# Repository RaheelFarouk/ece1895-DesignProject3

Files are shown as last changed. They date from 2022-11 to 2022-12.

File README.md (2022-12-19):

# **Design Project 3 – Designing a Live Telemetry System**

# Design Overview

This project was developed for ECE 1895 – Junior Design at the University of Pittsburgh.
 The purpose of this project was to develop a Live Telemetry system for use in Automotive and Motorsport applications. The live telemetry system is used to be able to analyse data from sensors and actuators on the vehicle remotely and in real time. It consists of a device called the Vehicle Telemetry Module (VTM) that goes inside a vehicle and connects to the CAN bus on the vehicle. The CAN bus is a network protocol used in automotive applications to send data and allow multiple devices to communicate with each other two wires. This Vehicle Telemetry Module then uses ethernet to connect to a 4G Router to send this data over the internet to a server that receives that data, and forwards it to the client (the data analysis workstation).

### Timeline

This was a six week project and this was the timeline I followed for the project:

- 1st week: Prototype and make CAN Bus code
- 2nd week: Start working on Ethernet Code
- 3rd week: Combine both CAN and Ethernet Code
- 4th week: Start working on server-side code to retrieve data
- 5th week: Test the system
- 6th week: Continue testing and debugging and 3D print enclosure

In the six weeks I was also able to work on a custom PCB for the vehicle telemetry module and also write a basic MATLAB script for the client side to receive data from the server.

### Vehicle Telemetry Module Considerations

The initial considerations for the vehicle telemetry module were as follows:

For the microprocessor I chose an ATMEGA328P, as it was the chip used in an Arduino and had both enough memory and processing power for the initial application. In addition, I also had an Arduino UNO available and thought it would be a good prototyping platform to get started on.

For the CAN bus communication, I chose an MCP2515 as the CAN controller and a MCP2551 for the CAN transceiver. Again, this decision was influenced by the fact that there was already a CAN shield developed for the Arduino and I had prior experience with using the SPI bus which is what this shield used to communicate with the Arduino. For this I used the autowp-mcp2515 library found here: [https://www.arduino.cc/reference/en/libraries/autowp-mcp2515/](https://www.arduino.cc/reference/en/libraries/autowp-mcp2515/)

For the Ethernet module I chose to use the Arduino Ethernet shield V2. This shield also used SPI to communicate with the ATMEGA328 Chip. Therefore, I decided to use it. I used the getting started guide on the Arduino website to get this ethernet shield to work with the Arduino. [https://docs.arduino.cc/tutorials/ethernet-shield-rev2/udp-send-receive-string](https://docs.arduino.cc/tutorials/ethernet-shield-rev2/udp-send-receive-string)

### Server Code Considerations

For the server code I decided to use python. This was because I had used python in the past and I found out that python already and an in-built library for UDP communication. Since it was in-built it also had great documentation that I was able to make use of. This was a fairly straight forward decision as I had never done anything like this in the past and didn't really know what other options there was, in the future I will look into this and see if there are any better options for the server-side code. [https://wiki.python.org/moin/UdpCommunication](https://wiki.python.org/moin/UdpCommunication)
[https://pythontic.com/modules/socket/udp-client-server-example](https://pythontic.com/modules/socket/udp-client-server-example)

### Client Code Considerations

At this time, I haven't decided what to do with the client-side interface; however, I had time at the end to do some basic coding in MATLAB to make a script that is able to connect to the server and get some data from the server.

# Preliminary Design Verification

## Hardware

For the initial prototype stage, I used an Arduino UNO with the Ethernet shield and the CAN shield.

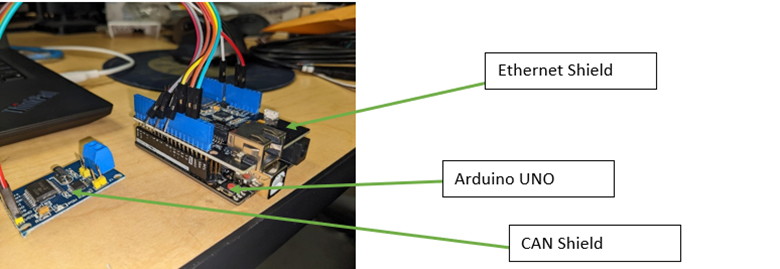
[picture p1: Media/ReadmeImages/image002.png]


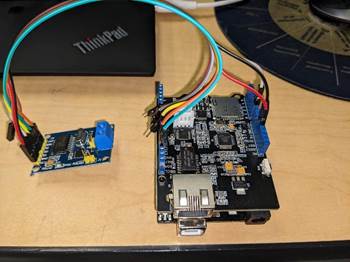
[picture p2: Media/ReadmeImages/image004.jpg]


## Software

I split this prototyping stage up into three parts. Firstly, I got the Arduino to read data from the CAN bus. Secondly, I got the Arduino to be able to send messages using UDP to a simple receive script that I made on the server. Thirdly, I combined the code to receive data from the CAN bus and then send it using the UDP protocol to the simple server script.

#### Reading CAN data using the Arduino

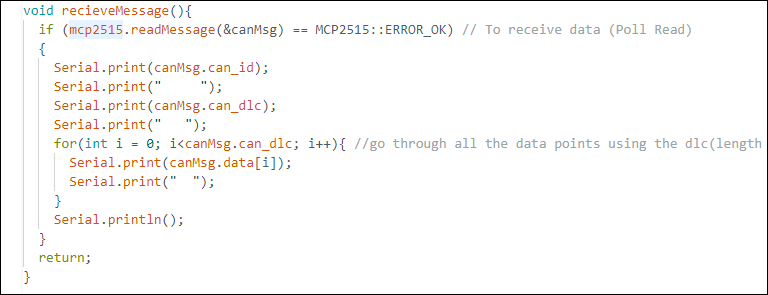
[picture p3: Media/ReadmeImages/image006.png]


_Receive Code Snippet_

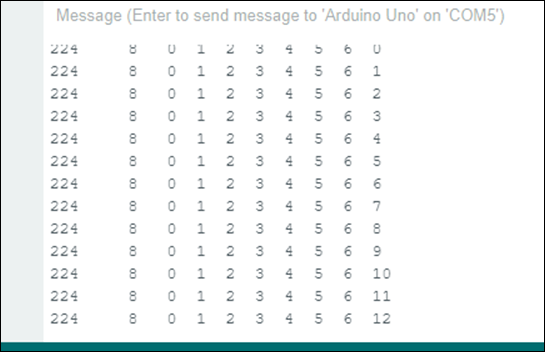
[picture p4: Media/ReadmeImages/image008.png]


_Serial Output_

As you can see in the above two images, I was able to read data from the CAN bus. The data being transferred on the CAN bus is just a basic counter in the last byte.

#### Sending Data using the UDP Protocol

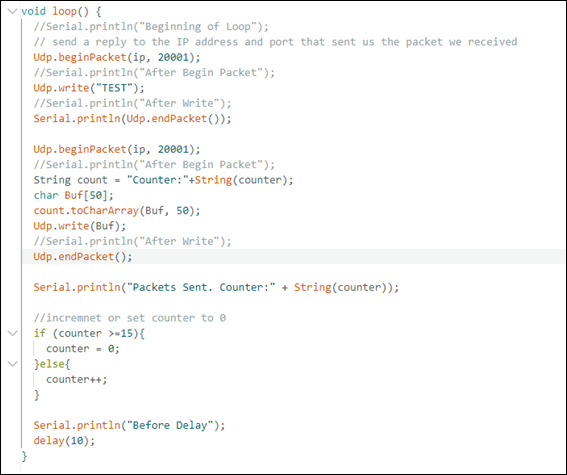
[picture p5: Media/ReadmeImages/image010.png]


_UDP Send Test code snippet_

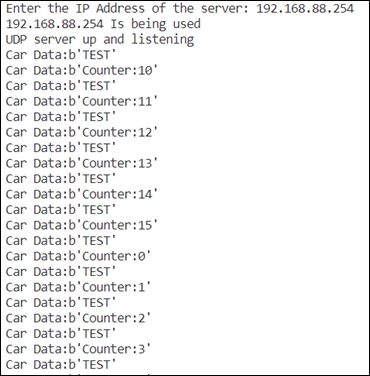
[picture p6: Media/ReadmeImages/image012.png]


_Console output on the server_

#### Receiving CAN Data and Sending it Using the UDP Protocol

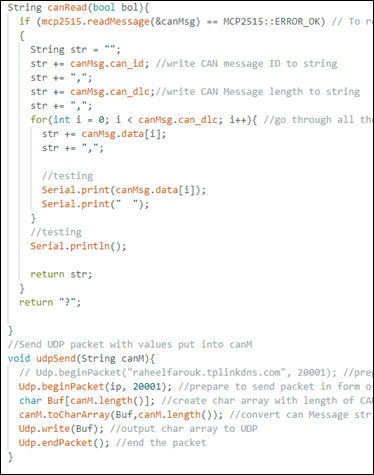
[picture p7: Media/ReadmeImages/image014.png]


_CAN data receive and send code snippet._

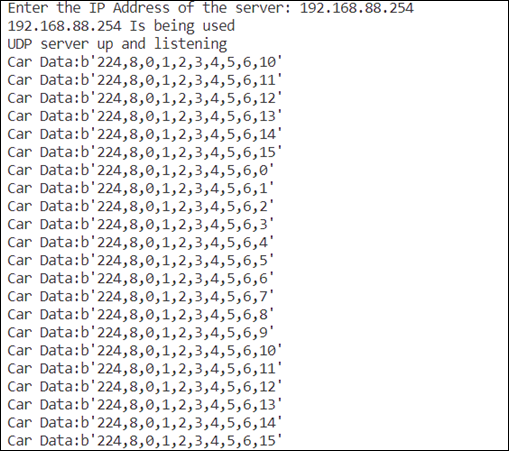
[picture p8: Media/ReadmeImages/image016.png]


 _Console output on the server._

# Design Implementation

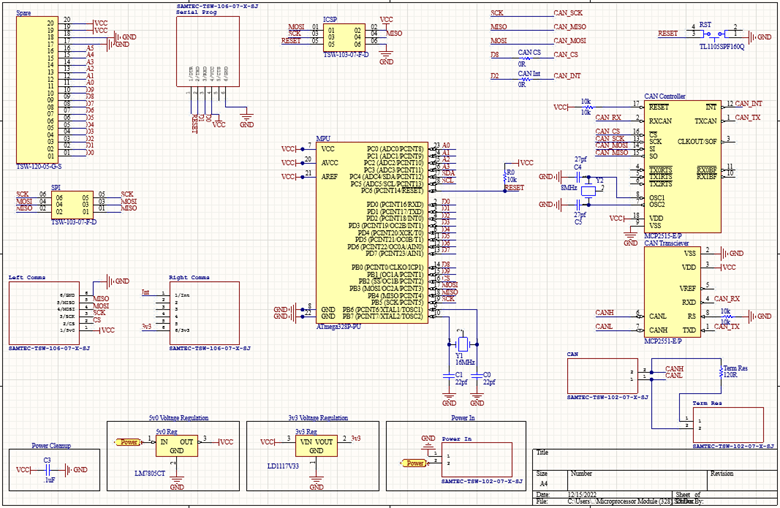
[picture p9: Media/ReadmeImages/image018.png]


_Schematic for the Microprocessor and CAN Chips_

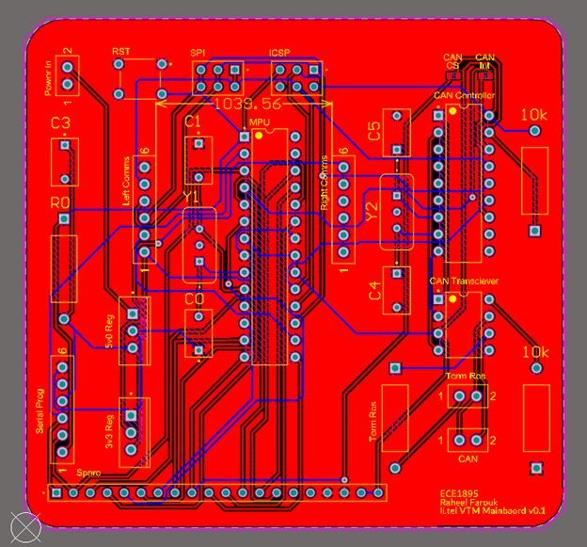
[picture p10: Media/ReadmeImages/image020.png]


_PCB Layout for the Microprocessor and CAN Chips_

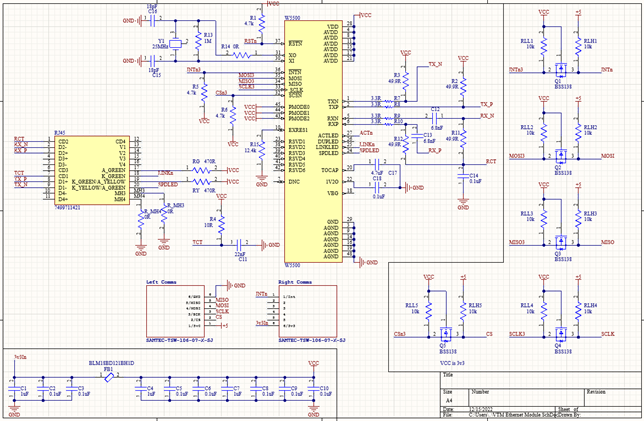
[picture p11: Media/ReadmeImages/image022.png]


_Schematic for the ethernet module_

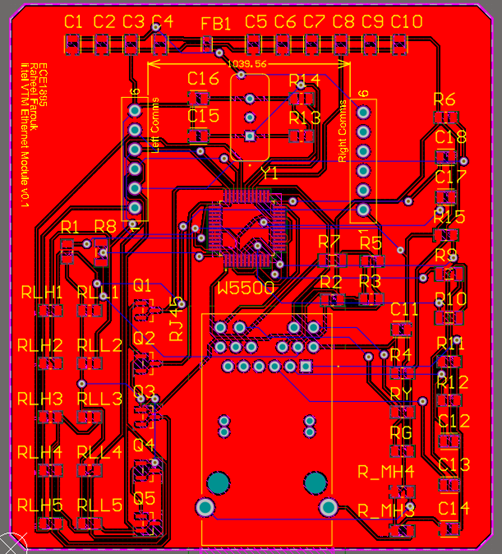
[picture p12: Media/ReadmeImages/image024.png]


_PCB Layout for the ethernet module_

# Design Testing

### Assembled Boards

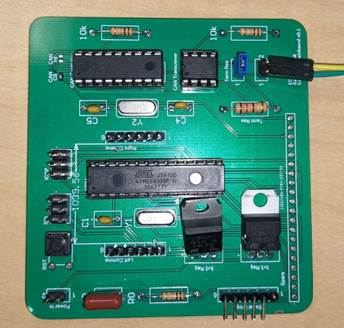
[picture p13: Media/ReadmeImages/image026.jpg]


_Main board with ATMEGA328 and CAN Chips_

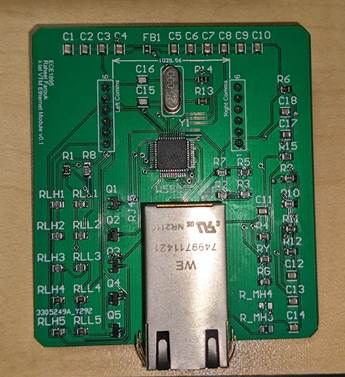
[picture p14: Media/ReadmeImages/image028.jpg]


_Ethernet Board_

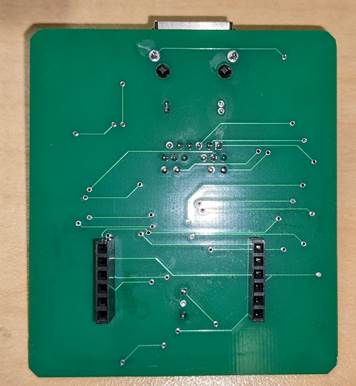
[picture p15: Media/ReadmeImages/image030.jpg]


_Underside of Ethernet board_

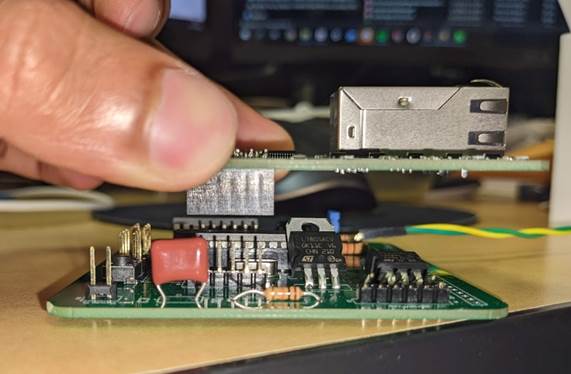
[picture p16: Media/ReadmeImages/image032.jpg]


_Plugging in the ethernet boards to the main board_

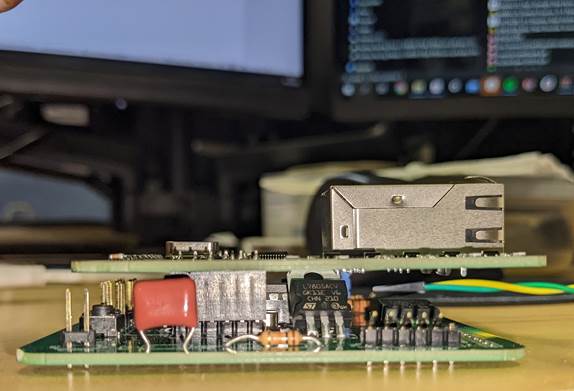
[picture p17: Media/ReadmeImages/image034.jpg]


_The complete stack_

### Testing

To test out the system I carried out the same tests that I did when initially prototyping the system. I used another development board to simulate the CAN bus on a vehicle and send CAN messages to my Vehicle Telemetry Module. I sent a basic message with a counter that sends an integer from 0 to 15 in the last byte of the CAN message. The development board that is set to simulate the car is set to send a CAN message every 50 milliseconds.



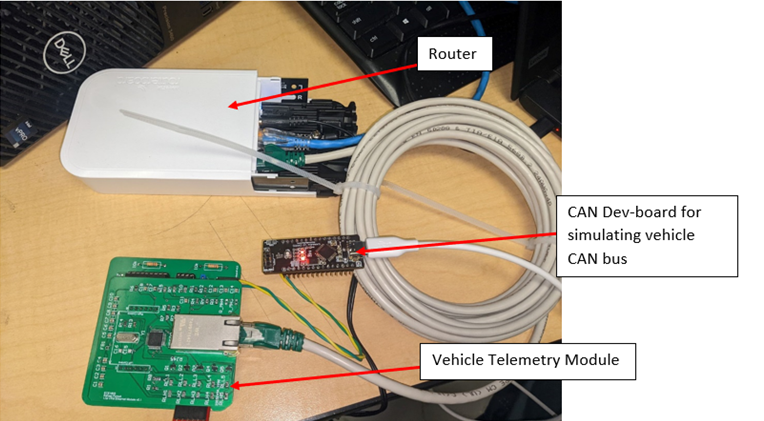
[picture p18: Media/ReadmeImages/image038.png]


_The test setup_

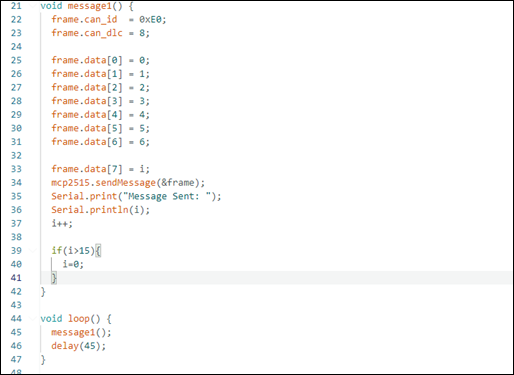
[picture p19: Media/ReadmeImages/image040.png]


 _Code for the CAN dev-board that is simulating the car_

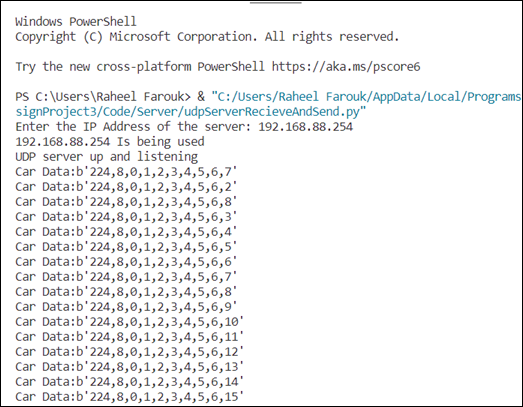
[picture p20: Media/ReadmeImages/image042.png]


 _Console output of the running code_

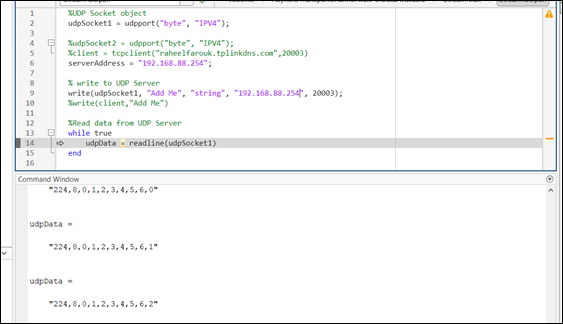
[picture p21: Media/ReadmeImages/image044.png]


 _Basic MATLAB Script reading broadcasted data from the server_

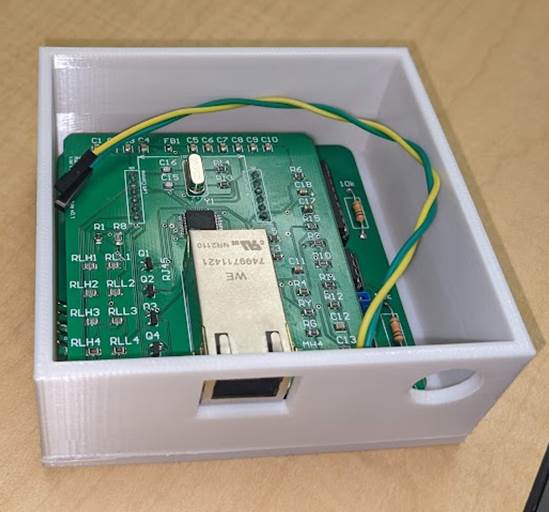
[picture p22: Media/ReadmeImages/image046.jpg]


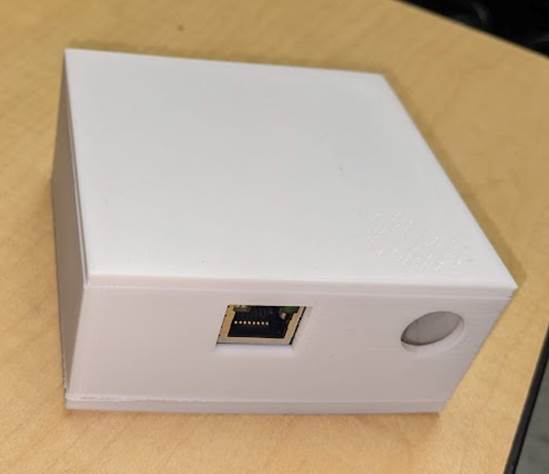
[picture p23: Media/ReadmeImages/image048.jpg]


 _3D printed enclosure for the Vehicle Telemetry Module_

# Summary, Conclusions and Future Work

In summary, the system works as it is intended. A few things that I would like to accomplish in the future is to make both my PCBs smaller and also possibly integrate it into one PCB. I had not taken into account the height and positions of certain components and had to therefore bend some components out of the way; this is something that I intent to fix in future versions. Another thing I would like to do is test out the data transfer rate at which messages are starting to be missed or lost. A future addition to the server-side code is to add a GUI and to make a client software to analyse the data. 

# Folder Structure

All the code for the live telemetry system is in the *Code* folder, the Vehicle Telemetry Code is inside the *Car* folder, the server code in the *Server* folder and the client code in the *Client* folder. The Altium PCB projects and enclosure CAD files are in the hardware folder. Any reference documents, schematics and libraries are in the *Datasheets and Reference Docs* folder.

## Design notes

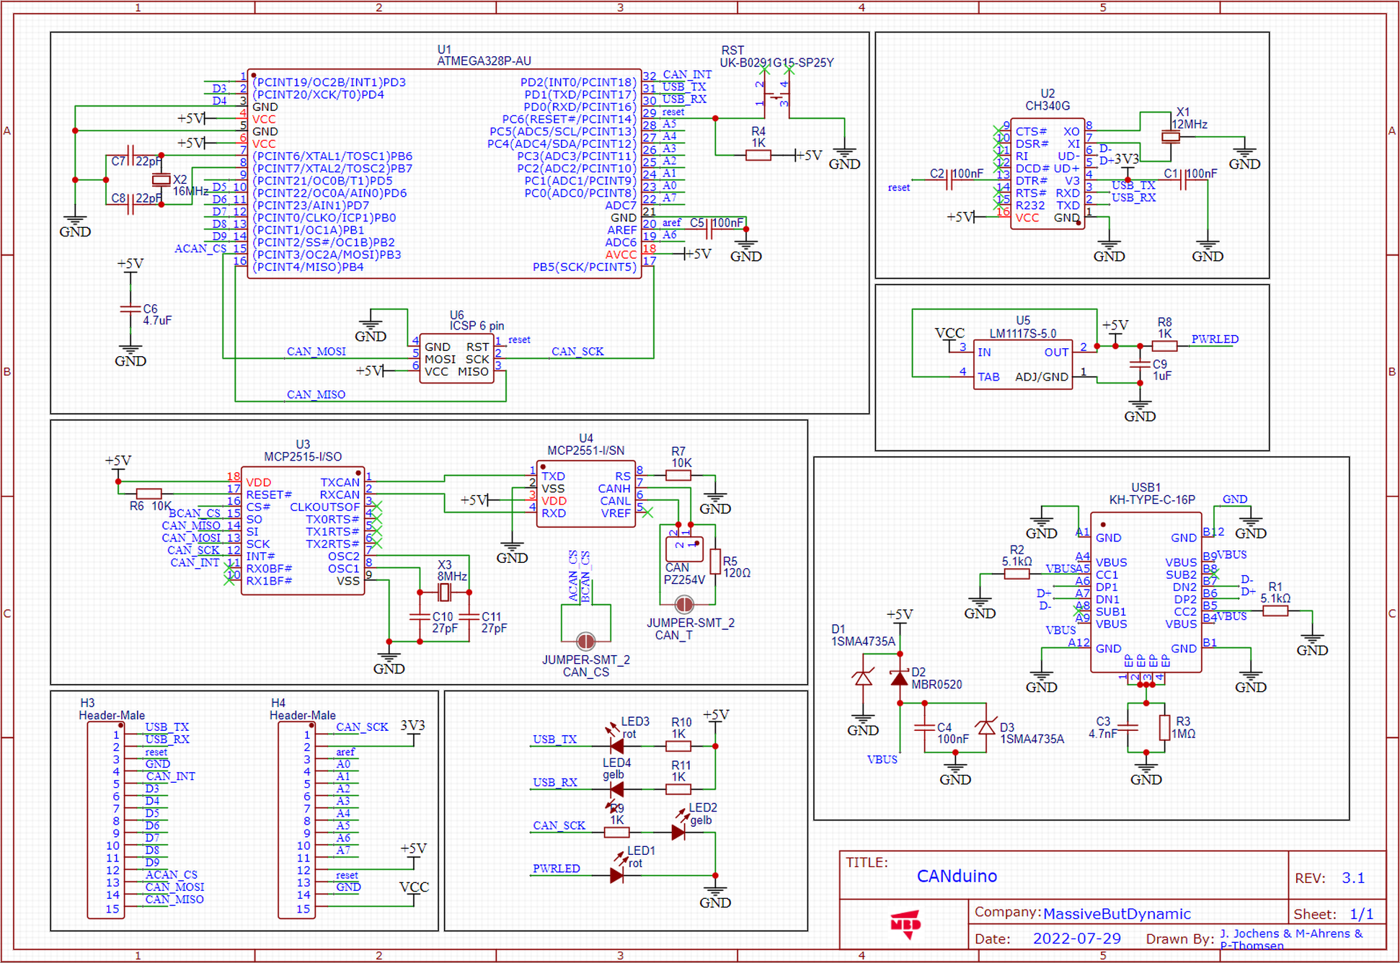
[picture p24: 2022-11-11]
Datasheets and Reference Docs/CANduino Schematic.png

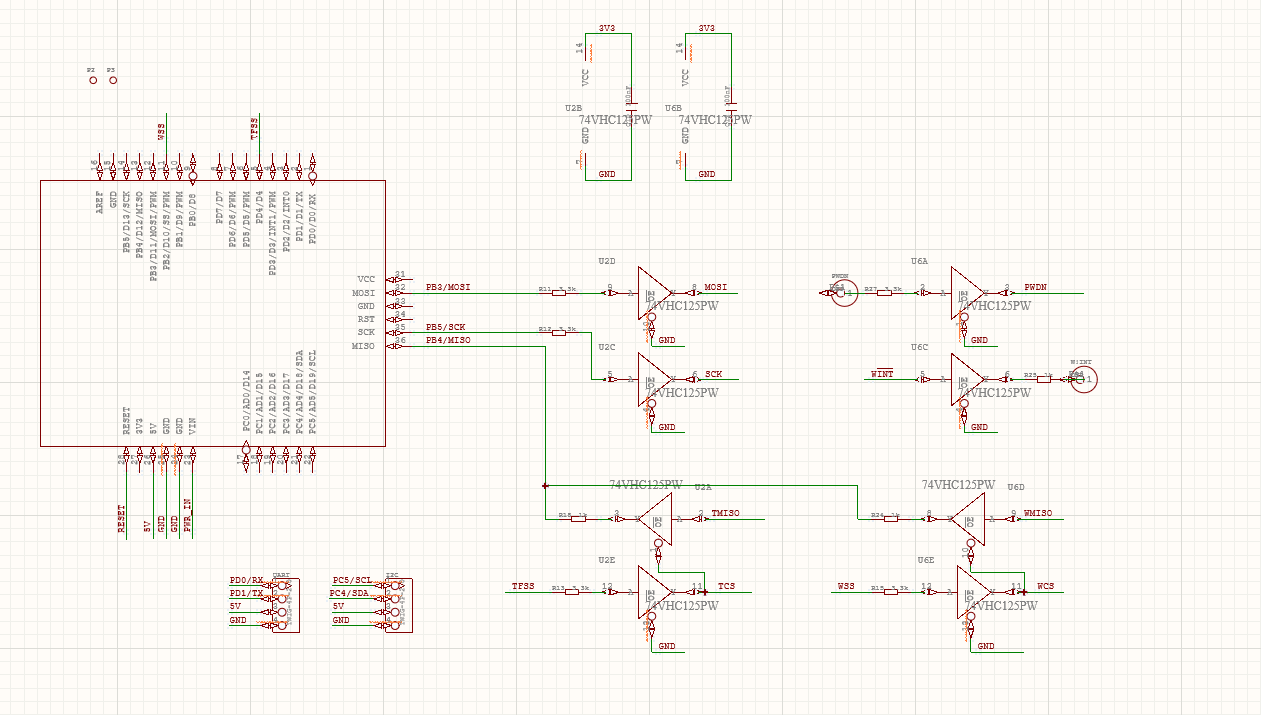
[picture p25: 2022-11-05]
Datasheets and Reference Docs/Arduino Ethernet Shield v2.0/Images/Screenshot 2022-10-31 183155.png

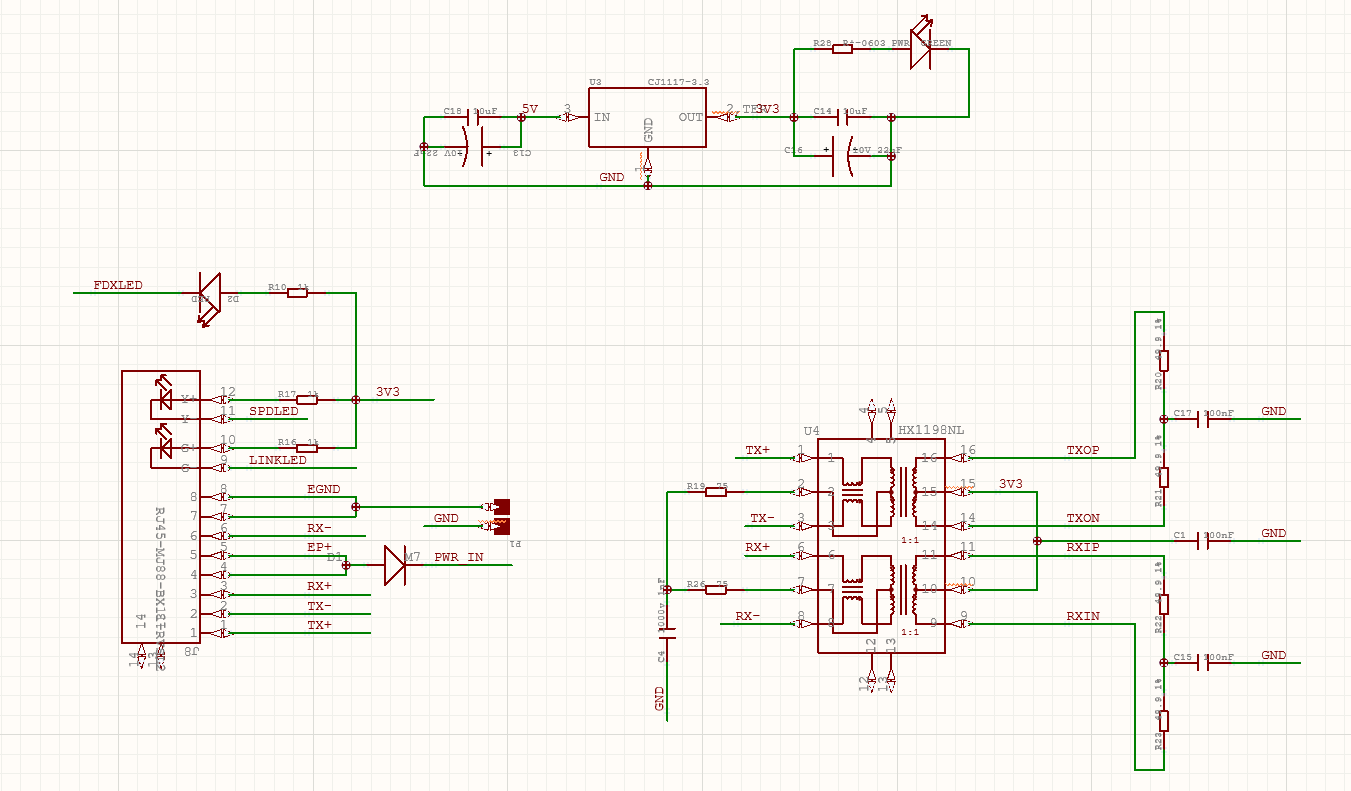
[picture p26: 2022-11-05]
Datasheets and Reference Docs/Arduino Ethernet Shield v2.0/Images/Screenshot 2022-10-31 183148.png

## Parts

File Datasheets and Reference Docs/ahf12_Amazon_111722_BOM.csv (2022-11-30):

Quantity | Link | Description | Pitt User ID | Unit Price | Extended Price
1 | https://www.amazon.com/HiLetgo-FT232RL-Converter-Adapter-Breakout/dp/B00IJXZQ7C | Serial Programmer | ahf12 | 6.49 | 6.49
1 | https://www.amazon.com/KeeYees-Channels-Converter-Bi-Directional-Shifter/dp/B07LG646VS?s=electronics | BSS138 Chip | ahf12 | 7.99 | 7.99
1 | https://www.amazon.com/uxcell-Crystal-Oscillators-Resonators-Replacements/dp/B07Y7GH8MD | Crystal Oscillator | ahf12 | 9.99 | 9.99
1 | https://www.amazon.com/Elegoo-EL-CP-004-Multicolored-Breadboard-arduino/dp/B01EV70C78 | Jumper Wires | ahf12 | 6.98 | 6.98

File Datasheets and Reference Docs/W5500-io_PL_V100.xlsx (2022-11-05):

W5500-io V100 Partlist
No | Quantity | Designator | Comment | Description | Pakage
1 | 3 | C1, C4, C7 | 1uF | 10V-5% Ceramic | CASE 0402
2 | 9 | C2, C3, C5, C6, C8, C9, C10, C14, C18 | 0.1uF | 50V-5% Ceramic | CASE 0402
3 | 1 | C11 | 22nF | 50V-5% Ceramic | CASE 0402
4 | 2 | C12, C13 | 6.8nF | 50V-5% Ceramic | CASE 0402
5 | 2 | C15, C16 | 18pF | 50V-5% Ceramic | CASE 0402
6 | 1 | C17 | 4.7uF | 16V-10%Ceramic | CASE 0805
7 | 1 | J1 | Not Mount
8 | 2 | J2, J3 | Not Mount
9 | 1 | L1 | HH-1M1608-121JT | Bead for Power Line, 120[ohm] | CASE 0603
10 | 3 | R1, R5, R6 | 4.7K | 1/10W-1% SMD | CASE 0402
11 | 4 | R2, R3, R11, R12 | 49.9R | 1/10W-1% SMD | CASE 0402
12 | 1 | R4 | 10R | 1/10W-1% SMD | CASE 0402
13 | 4 | R7, R8, R9, R10 | 3.3R | 1/10W-1% SMD | CASE 0402
14 | 1 | R13 | 1M | 1/10W-1% SMD | CASE 0402
15 | 1 | R14 | 0R | 1/10W-1% SMD | CASE 0402
16 | 1 | R15 | 12.4K | 1/10W-1% SMD | CASE 0402
17 | 1 | U1 | W5500 | WIZnet Hardwired TCP/IP Chip | W5500-LQFP48
18 | 1 | Y1 | 25MHz | X-tal 25MHz,3.2x2.5 SMD, CL=18pF | SMD3225, 4-PAD
19 | 1 | PCB | 20 X 24 (MM), 4-Layer, 1.0T, 1oz, FR-4, OSP, PCB: Matt Black, Silk: White

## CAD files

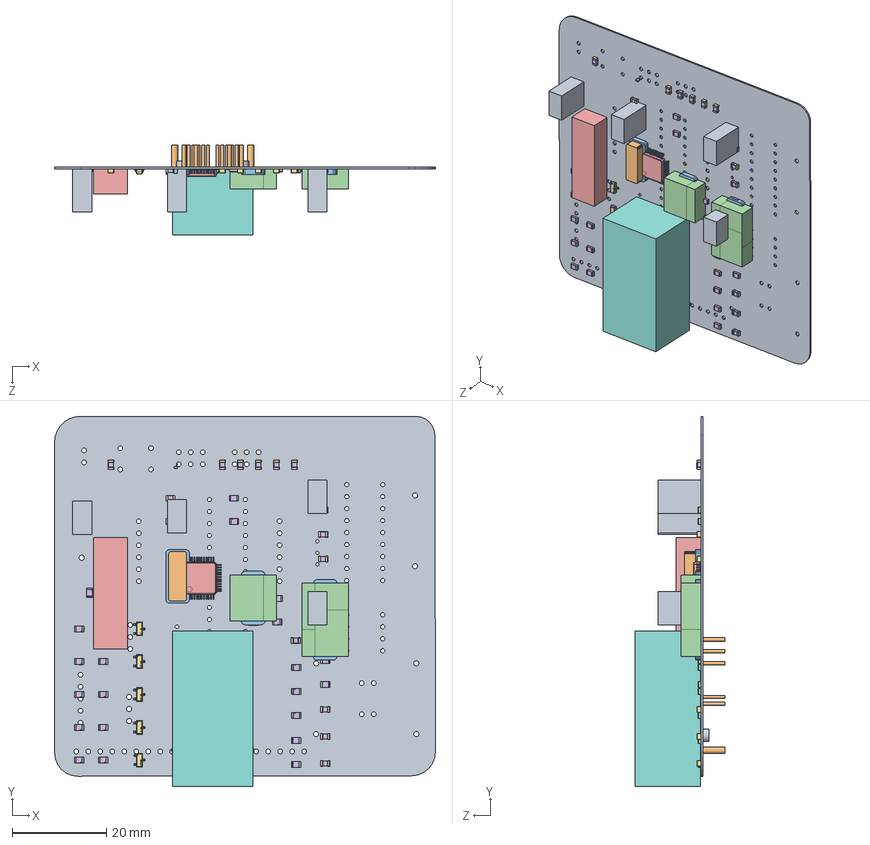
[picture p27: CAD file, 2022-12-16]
Hardware/CAD/VTM Ethernet Module.step.SLDASM
80.7 x 78.5 x 19.0 mm
Extruded.step
Extruded-0.step
1.step x 25
2.step x 25
3.step x 25
TE connectivity Logo 1 (2).step x 25
Body.step
Lugs.step
Leads.step
Extruded-1.step x 3
Extruded-2.step x 6
Extruded-3.step
Extruded-4.step x 2
1-5.step x 5
2-6.step x 5
ON Semi Logo - withoutPN.step x 5
ON Semi Logo - withoutPN - Copy.step x 5
6024908304.step
Cap_KEMET_C0805C472J3HAC_eec.step x 14
Cap_KEMET_C0805C472J3HAC_eec-7.step x 14
Cap_KEMET_C0805C472J3HAC_eec-8.step x 14
Extruded-14.step x 4

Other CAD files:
Hardware/CAD/R8.step.SLDASM
Hardware/CAD/R2.step.SLDASM
Hardware/CAD/Q4.step.SLDASM
Hardware/CAD/R4.step.SLDASM
Hardware/CAD/C18.step.SLDASM
Hardware/CAD/Q5.step.SLDASM
Hardware/CAD/FB1.step.SLDASM
Hardware/CAD/C11.step.SLDASM
Hardware/CAD/C7.step.SLDASM
Hardware/CAD/R1.step.SLDASM
Hardware/CAD/RLL5.step.SLDASM
Hardware/CAD/RLL3.step.SLDASM
Hardware/CAD/FBead_Murata_BLM18EG221SN1D_eec.step.SLDASM
Hardware/CAD/RLH3.step.SLDASM
Hardware/CAD/Q2.step.SLDASM
Hardware/CAD/R9.step.SLDASM
Hardware/CAD/R14.step.SLDASM
Hardware/CAD/1-5.step.SLDPRT
Hardware/CAD/1.step.SLDPRT
Hardware/CAD/2-6.step.SLDPRT
Hardware/CAD/2.step.SLDPRT
Hardware/CAD/3.step.SLDPRT
Hardware/CAD/3Dprint/body.3MF
Hardware/CAD/3Dprint/lid.3MF
Hardware/CAD/6024888384.step.SLDASM
Hardware/CAD/6024888544.step.SLDASM
Hardware/CAD/6024890784.step.SLDASM
Hardware/CAD/6024891024.step.SLDASM
Hardware/CAD/6024908304.step.SLDPRT
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

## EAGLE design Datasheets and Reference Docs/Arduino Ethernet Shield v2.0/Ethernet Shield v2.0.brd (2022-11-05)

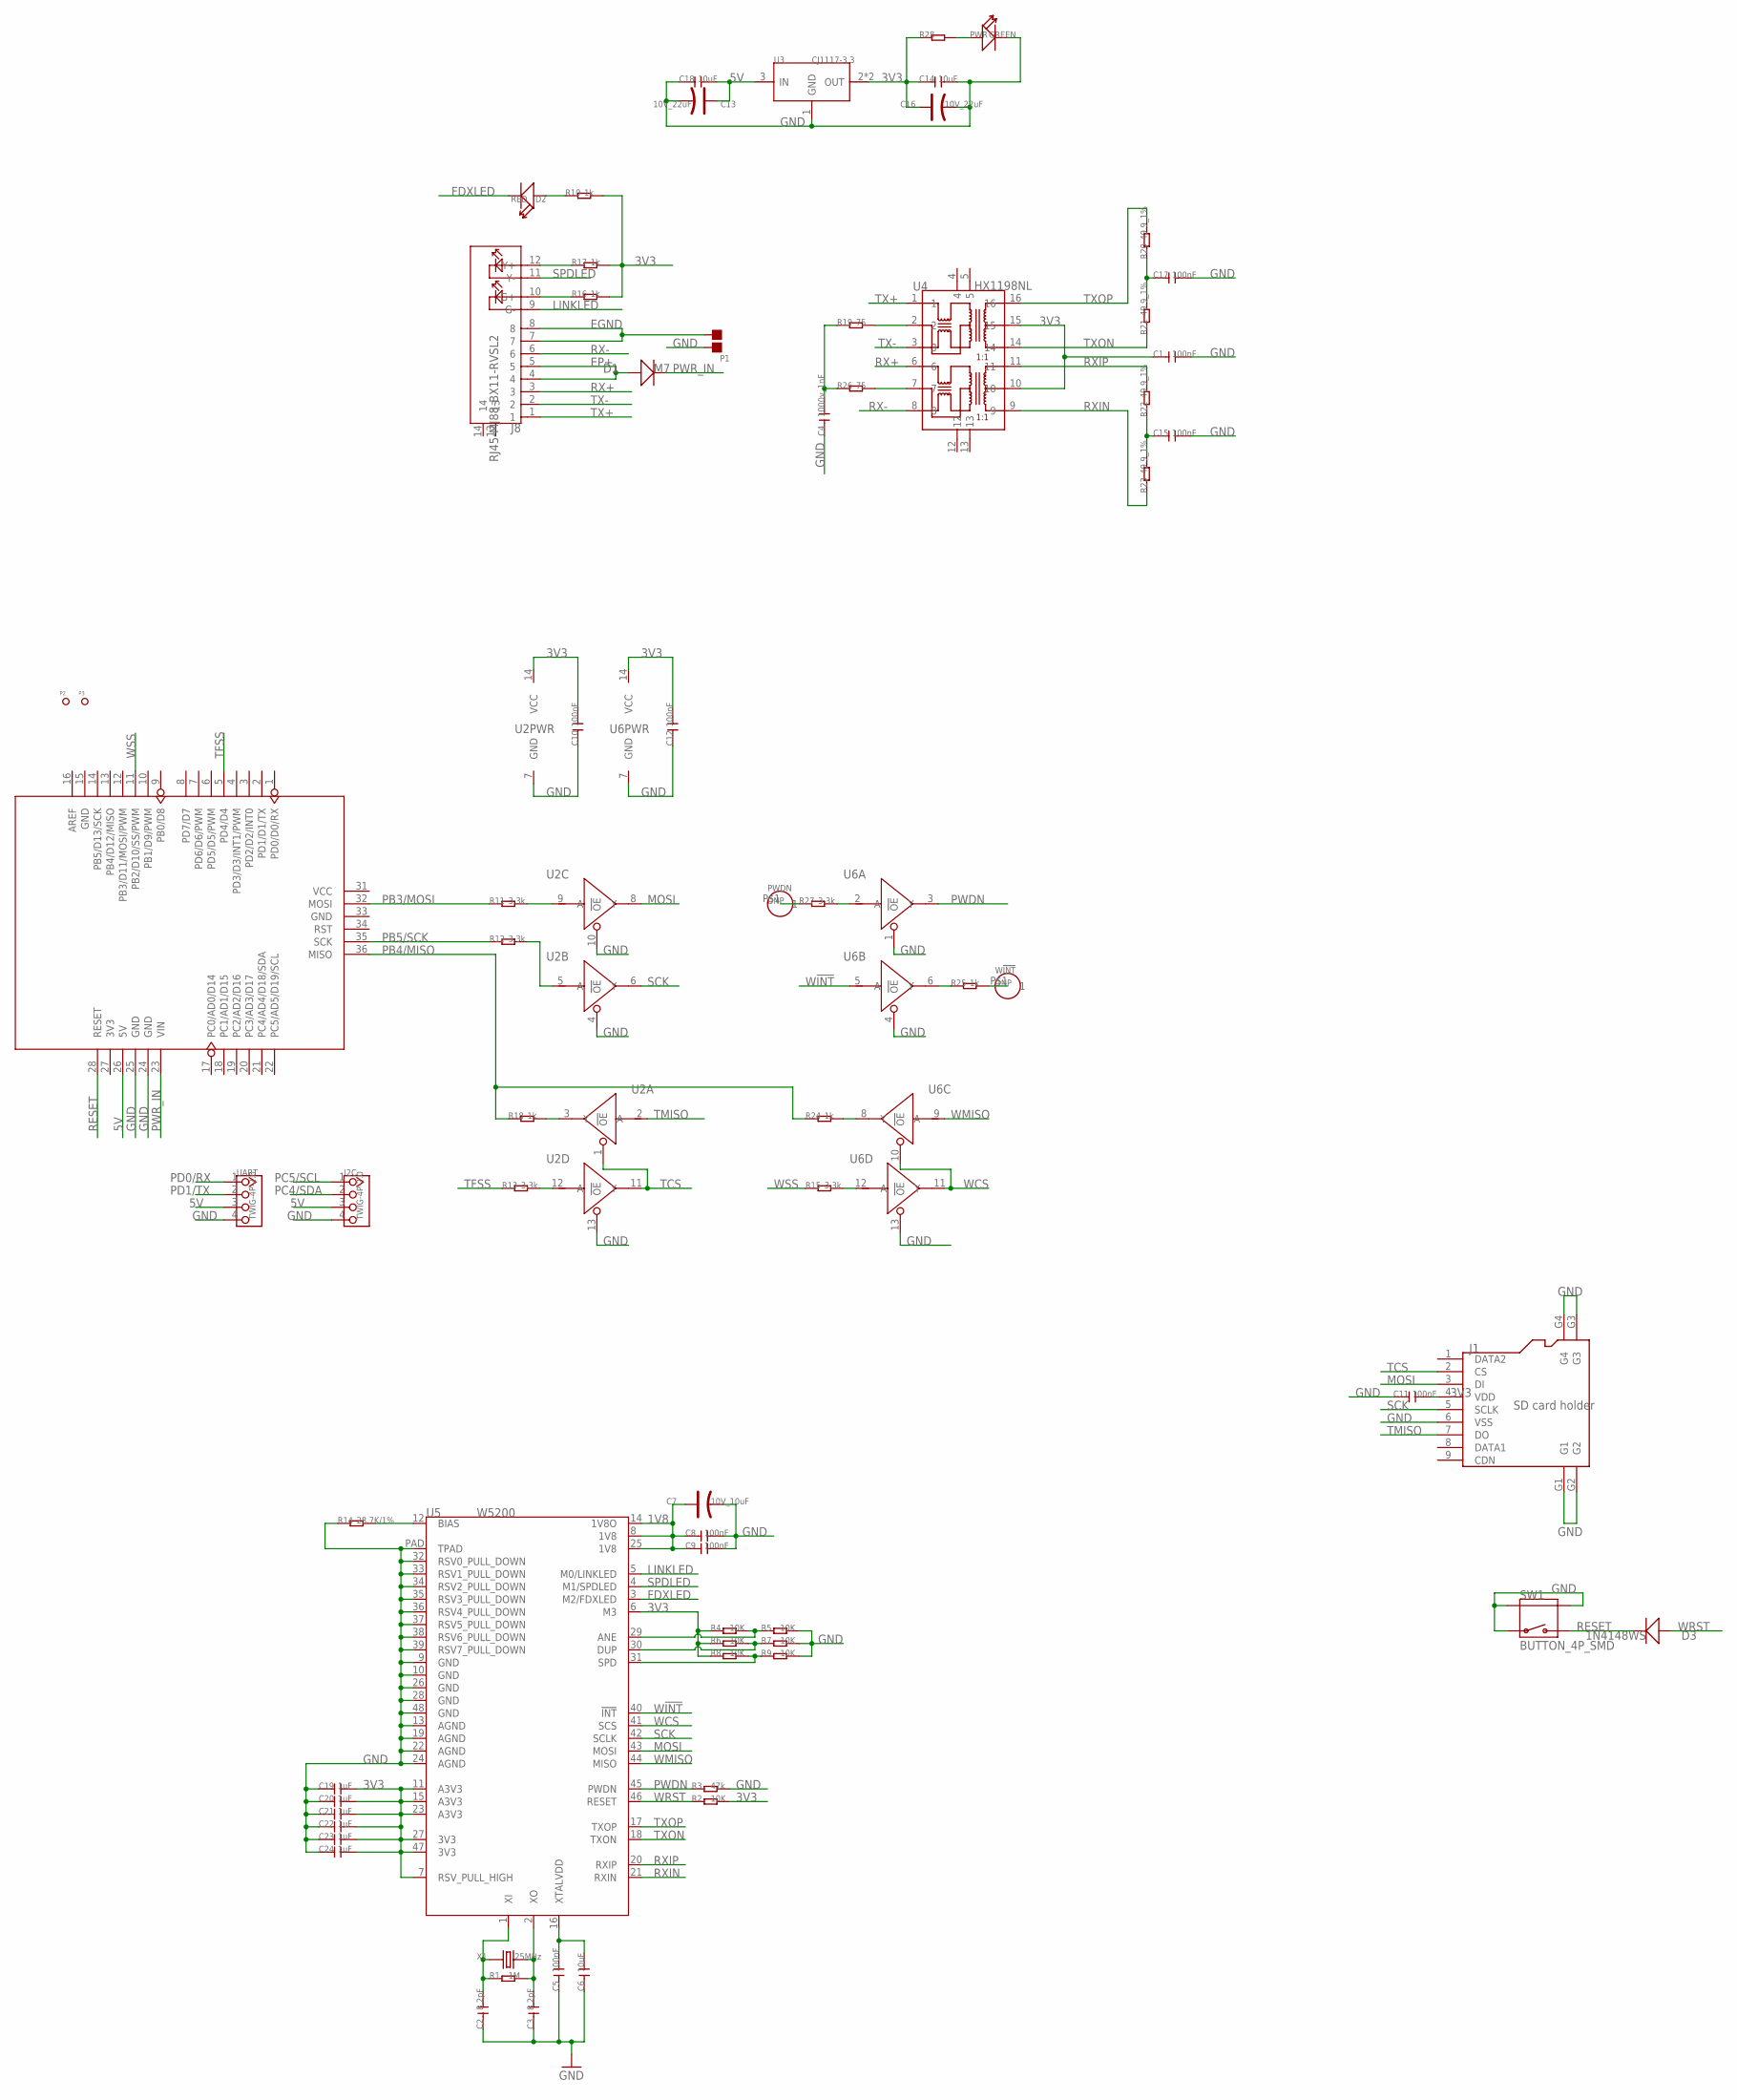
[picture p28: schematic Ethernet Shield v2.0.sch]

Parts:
C1, C5, C8, C9, C10, C11, C12, C15, C17: 100nF; C0603
C2, C3: 8.2pF; C0603
C4: 1000v_1nF; C1206
C6, C14, C18: 10uF; C0805
C7: 10V_10uF; AVX-A
C13, C16: 10V_22uF; AVX-B
C19, C20, C21, C22, C23, C24: 1uF; C0805
D1: M7; D2010
D2: RED; LED-0603
D3: 1N4148WS; SOD323
I2C: TWIG-4P-2.0; 4P-2.0
J1: SD card holder; 9P-SMD-W/-RING
J8: RJ45-MJ88-BX11-RVSL2
P1: DNP; 2P-SMD-1.78X1.27
P2, P3: PAD-MARK; ROUND-MARK-1.0
PWDN: DNP; 1P-65/35MIL
PWR: GREEN; LED-0603
R1: 1M; R0603
R2, R4, R5, R6, R7, R8, R9: 10K; R0603
R3: 47k; R0603
R10, R16, R17, R18, R24, R25: 1k; R0603
R11, R12, R13, R15, R27: 3.3k; R0603
R14: 28.7K/1%; R0603
R19, R26: 75; R0603
R20, R21, R22, R23: 49.9_1%; R0603
R28: R-0603; R0603
SW1: BUTTON_4P_SMD; 4P-SMD-7X3.5X3.5
U1: ARDUINO
U2, U6: 74VHC125PW; TSSOP14
U3: CJ1117-3.3; SOT-223
U4: HX1198NL; SOIC16-9.53
U5: W5200; QFN48
UART: TWIG-4P-2.0; 4P-2.0
W!INT: DNP; 1P-65/35MIL
X1: 25MHz; 2P-SMD-5X3.2

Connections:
1V8: C7.+, C8.1, C9.1, U5.8 (1V8), U5.14 (1V8O), U5.25 (1V8)
3V3: C1.1, C10.2, C11.2, C12.2, C14.1, C16.+, C19.2, C20.2, C21.2, C22.2, C23.2, C24.2, J1.4 (VDD), R2.2, R4.1, R6.1, R8.1, R10.2, R16.2, R17.2, R28.1, U2.14 (VCC), U3.2 (OUT), U3.TER (OUT), U4.10, U4.15, U5.6 (M3), U5.7 (RSV_PULL_HIGH), U5.11 (A3V3), U5.15 (A3V3), U5.23 (A3V3), U5.27 (3V3), U5.47 (3V3), U6.14 (VCC)
5V: C13.+, C18.2, I2C.3, U1.26 (5V), U3.3 (IN), UART.3
EGND: J8.7, J8.8, P1.1
EP+: D1.+, J8.4, J8.5
FDXLED: D2.-, U5.3 (M2/FDXLED)
GND: C1.2, C2.1, C3.1, C4.1, C5.1, C6.1, C7.-, C8.2, C9.2, C10.1, C11.1, C12.1, C13.-, C14.2, C15.2, C16.-, C17.2, C18.1, C19.1, C20.1, C21.1, C22.1, C23.1, C24.1, I2C.4, J1.6 (VSS), J1.G1, J1.G2, J1.G3, J1.G4, P1.2, PWR.-, R3.2, R5.2, R7.2, R9.2, R14.1, SW1.1, SW1.S1, SW1.S2, U1.24 (GND), U1.25 (GND), U2.4 (!OE), U2.7 (GND), U2.10 (!OE), U2.13 (!OE), U3.1 (GND), U5.9 (GND), U5.10 (GND), U5.13 (AGND), U5.19 (AGND), U5.22 (AGND), U5.24 (AGND), U5.26 (GND), U5.28 (GND), U5.32 (RSV0_PULL_DOWN), U5.33 (RSV1_PULL_DOWN), U5.34 (RSV2_PULL_DOWN), U5.35 (RSV3_PULL_DOWN), U5.36 (RSV4_PULL_DOWN), U5.37 (RSV5_PULL_DOWN), U5.38 (RSV6_PULL_DOWN), U5.39 (RSV7_PULL_DOWN), U5.48 (GND), U5.PAD (TPAD), U6.1 (!OE), U6.4 (!OE), U6.7 (GND), U6.13 (!OE), UART.4
LINKLED: J8.9 (G-), U5.5 (M0/LINKLED)
MOSI: J1.3 (DI), U2.8 (Y), U5.43 (MOSI)
unnamed: C2.2, R1.1, U5.1 (XI), X1.1
unnamed: C3.2, R1.2, U5.2 (XO), X1.2
unnamed: R4.2, R5.1, U5.29 (ANE)
unnamed: R6.2, R7.1, U5.30 (DUP)
unnamed: R8.2, R9.1, U5.31 (SPD)
unnamed: D2.+, R10.1
unnamed: R12.2, U2.5 (A)
unnamed: R11.2, U2.9 (A)
unnamed: R13.2, U2.12 (A)
unnamed: R15.2, U6.12 (A)
unnamed: R26.2, U4.7
unnamed: R19.2, U4.2
unnamed: C4.2, R19.1, R26.1
unnamed: R18.2, U2.3 (Y)
unnamed: C15.1, R22.1, R23.2
unnamed: C17.1, R20.1, R21.2
unnamed: R24.2, U6.8 (Y)
unnamed: J8.12 (Y+), R17.1
unnamed: J8.10 (G+), R16.1
unnamed: R25.1, U6.6 (Y)
unnamed: R25.2, W!INT.P$1
unnamed: C5.2, C6.2, U5.16 (XTALVDD)
unnamed: R14.2, U5.12 (BIAS)
unnamed: R27.2, U6.2 (A)
unnamed: PWDN.P$1, R27.1
unnamed: PWR.+, R28.2
PB3/MOSI: R11.1, U1.32 (MOSI)
PB4/MISO: R18.1, R24.1, U1.36 (MISO)
PB5/SCK: R12.1, U1.35 (SCK)
PC4/SDA: I2C.2
PC5/SCL: I2C.1
PD0/RX: UART.1
PD1/TX: UART.2
PWDN: R3.1, U5.45 (PWDN), U6.3 (Y)
PWR_IN: D1.-, U1.23 (VIN)
RESET: D3.-, SW1.2, U1.28 (RESET)
RX+: J8.3, U4.6
RX-: J8.6, U4.8
RXIN: R23.1, U4.9, U5.21 (RXIN)
RXIP: R22.2, U4.11, U5.20 (RXIP)
SCK: J1.5 (SCLK), U2.6 (Y), U5.42 (SCLK)
SPDLED: J8.11 (Y-), U5.4 (M1/SPDLED)
TCS: J1.2 (CS), U2.1 (!OE), U2.11 (Y)
TFSS: R13.1, U1.5 (PD4/D4)
TMISO: J1.7 (DO), U2.2 (A)
TX+: J8.1, U4.1
TX-: J8.2, U4.3
TXON: R21.1, U4.14, U5.18 (TXON)
TXOP: R20.2, U4.16, U5.17 (TXOP)
W!INT: U5.40 (!INT), U6.5 (A)
WCS: U5.41 (SCS), U6.10 (!OE), U6.11 (Y)
WMISO: U5.44 (MISO), U6.9 (A)
WRST: D3.+, R2.1, U5.46 (RESET)
WSS: R15.1, U1.11 (PB2/D10/SS/PWM)

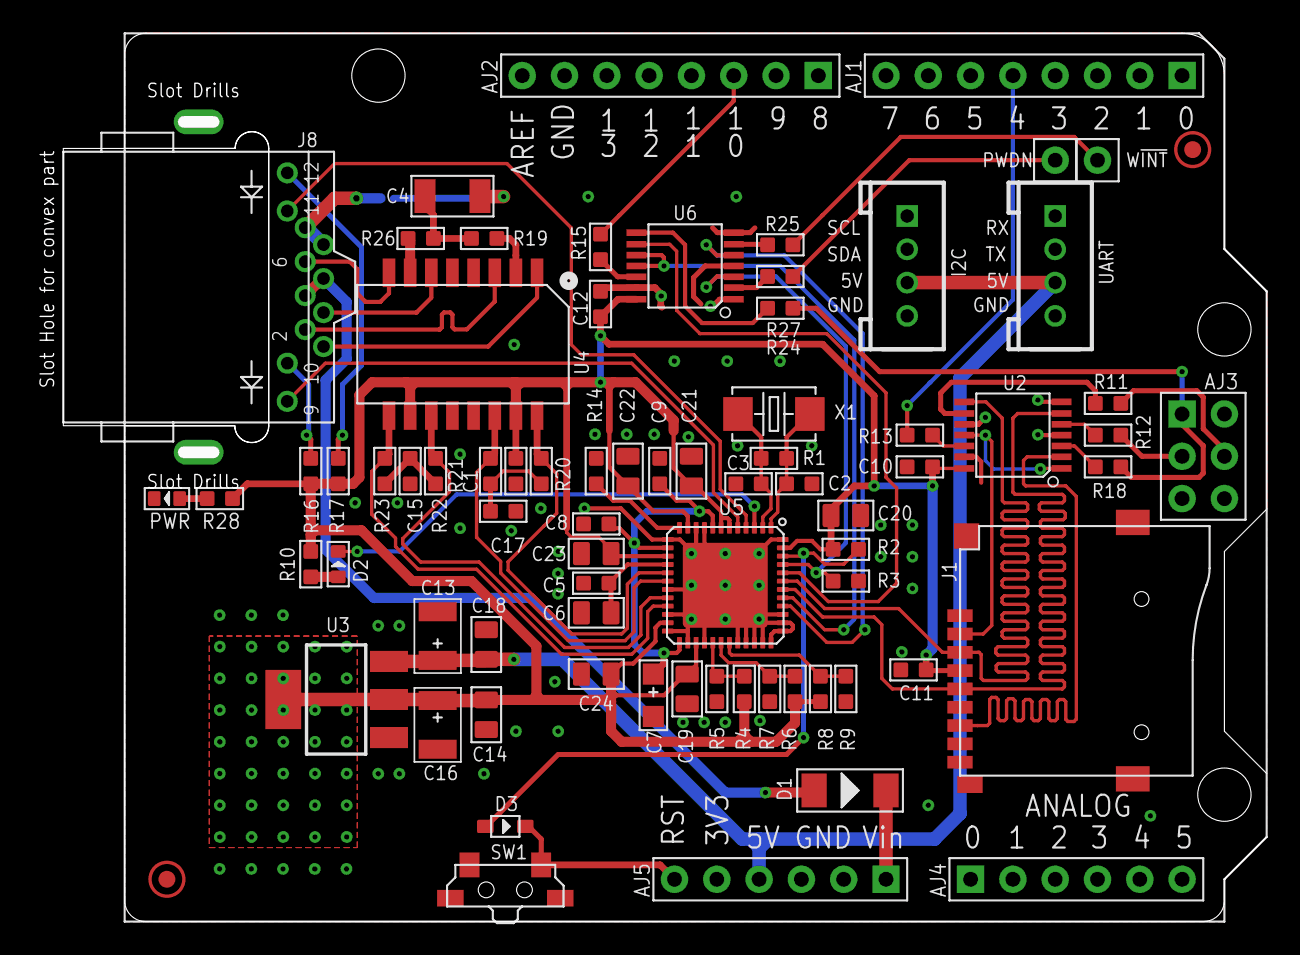
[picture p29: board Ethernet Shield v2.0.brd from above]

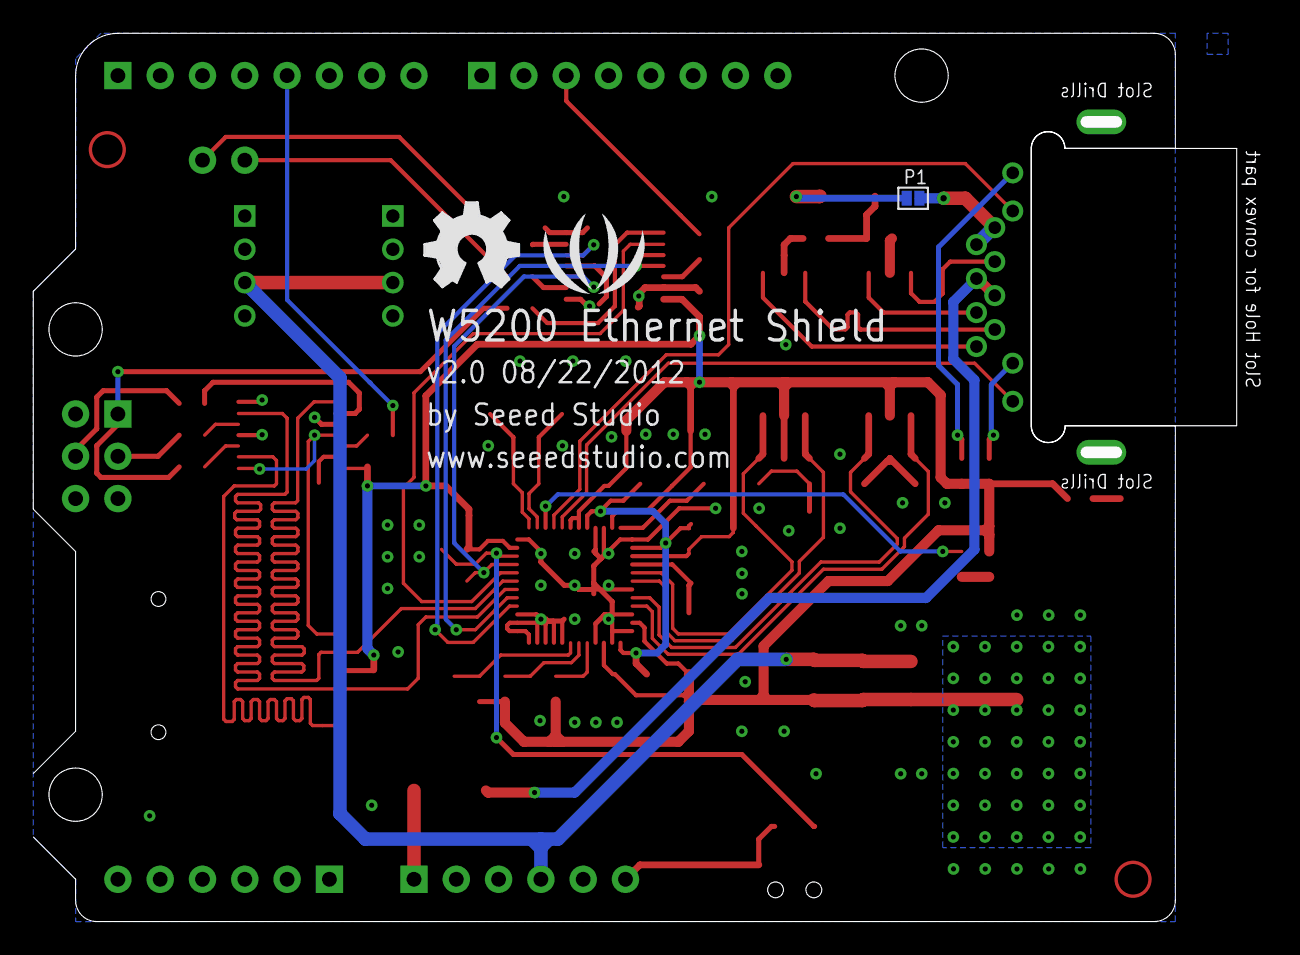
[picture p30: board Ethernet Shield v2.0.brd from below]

Board: 2 copper layers, 72.3 x 53.3 mm, 75 parts (3 on the bottom side), 59 nets.

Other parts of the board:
U$1: LOGO_SILK
U$2: OSHW_FILLX200_NOTEXT

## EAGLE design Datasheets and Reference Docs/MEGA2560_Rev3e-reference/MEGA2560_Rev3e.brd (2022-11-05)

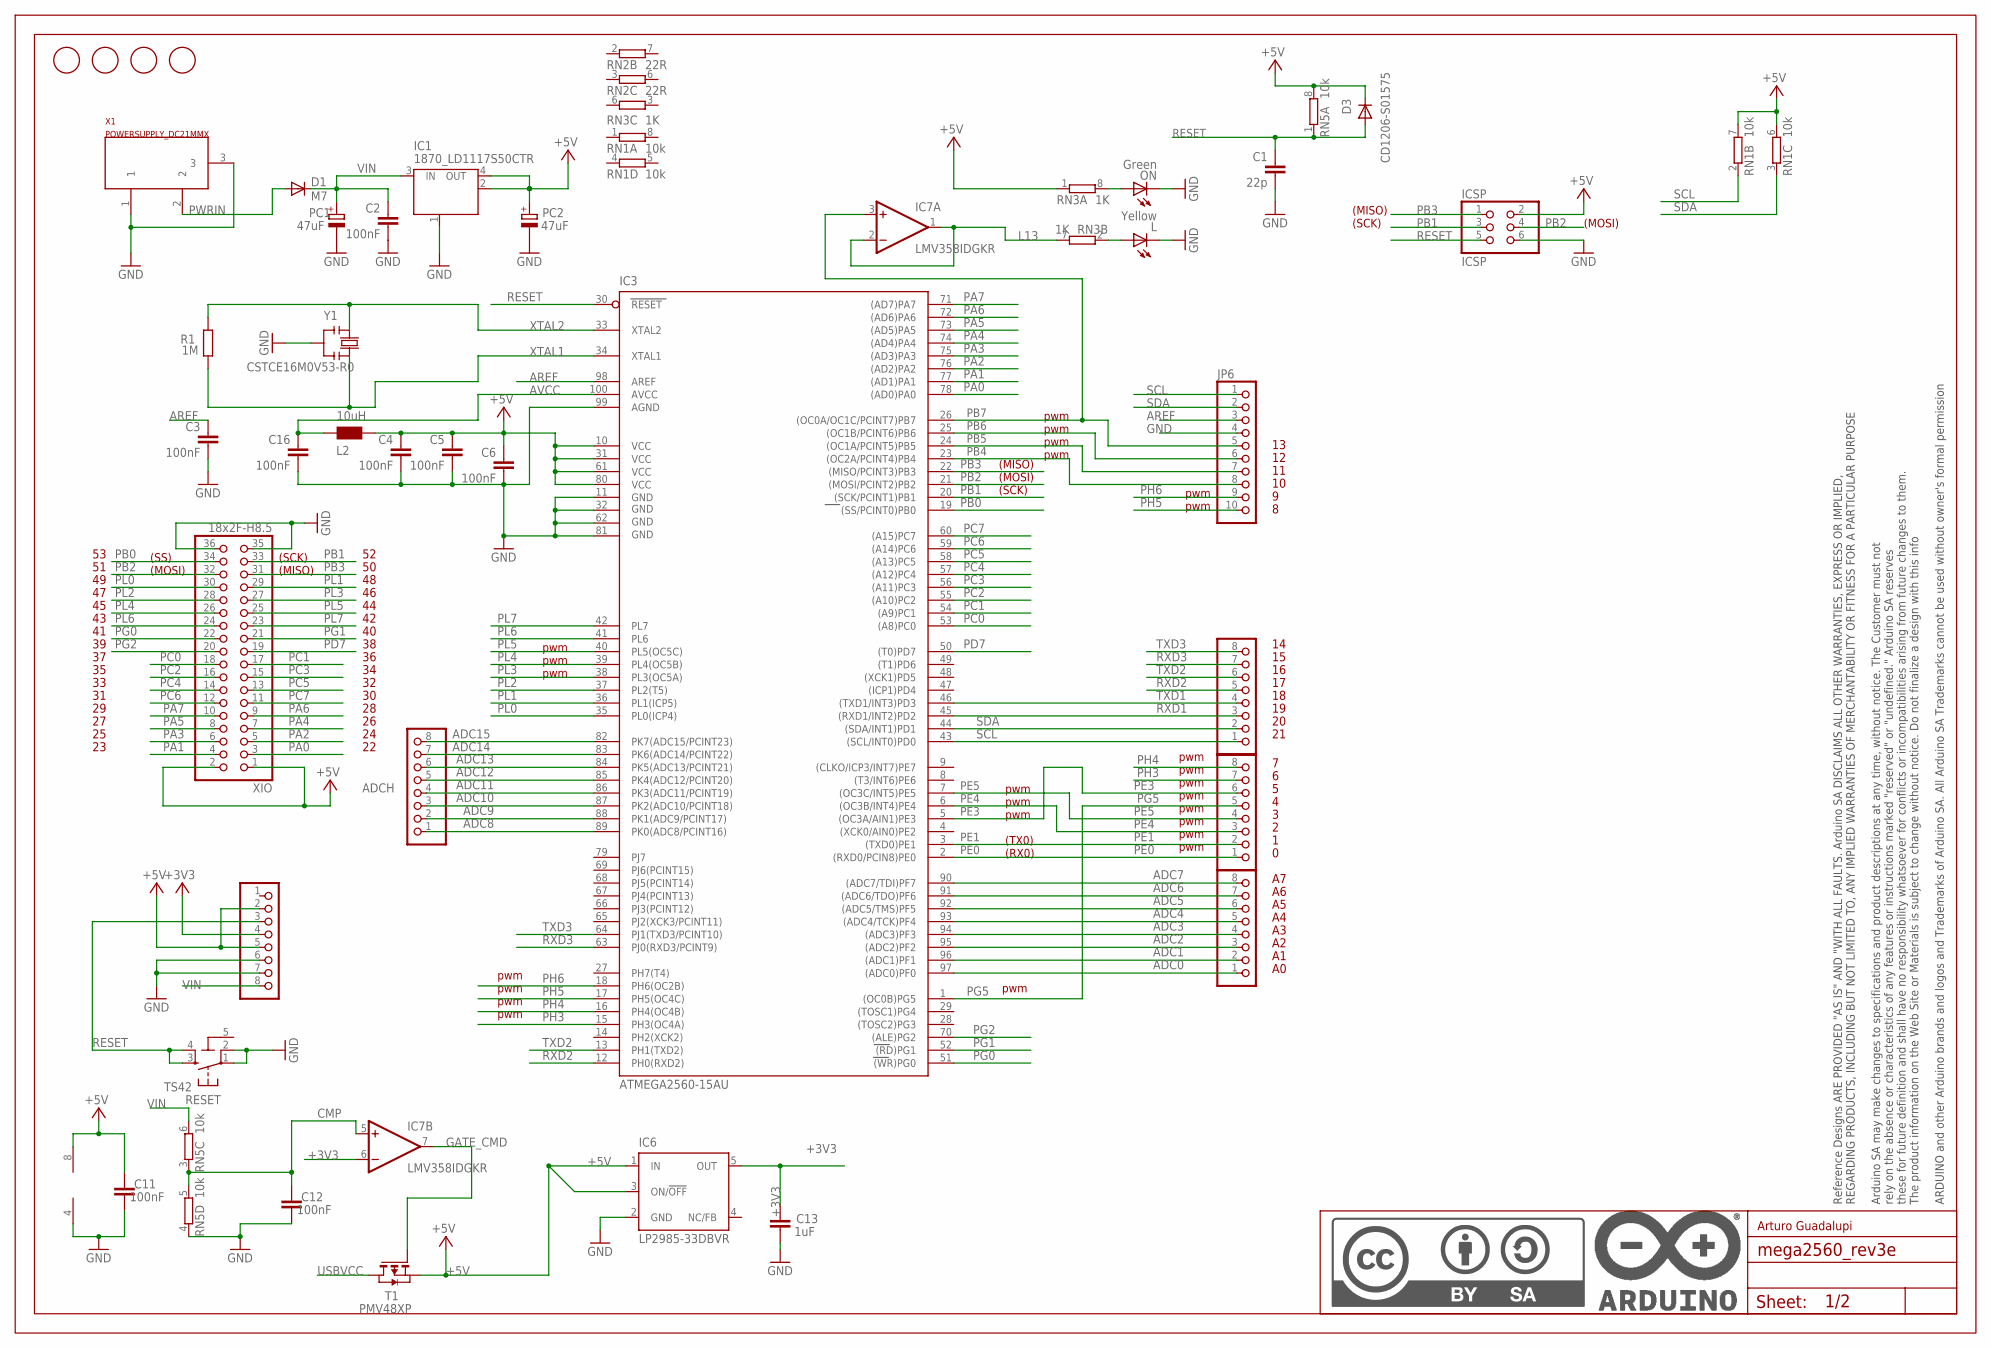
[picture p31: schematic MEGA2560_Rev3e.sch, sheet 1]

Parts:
ADCH: FH254-108DF08500V; 1X08
ADCL: FH254-108DF08500V; 1X08
C1: 22p; C0603-ROUND
C2, C3, C4, C5, C6, C11, C12, C16: 100nF; C0603-ROUND
C13: 1uF; C0603-ROUND
COMMUNICATION: FH254-108DF08500V; 1X08
D1: M7; SMB
D3: CD1206-S01575; MINIMELF
FD1, FD2, FD3, FD4: FIDUCIALMOUNT; FIDUCIA-MOUNT
IC1: 1870_LD1117S50CTR; LINEAR_SOT223
IC3: ATMEGA2560-15AU; TQFP100
IC6: LP2985-33DBVR; SOT23-DBV
IC7: LMV358IDGKR; MSOP08
ICSP: ICSP; 2X03
JP6: FH254-110DF08500V; 1X10
L: Yellow; CHIPLED_0805
L2: 10uH; 0805
ON: Green; CHIPLED_0805
PC1, PC2: 47uF; PANASONIC_D
POWER: FH254-108DF08500V; 1X08
PWML: FH254-108DF08500V; 1X08
R1: 1M; R0603-ROUND
RESET: TS42
RN1, RN5: 10k; CAY16
RN2: 22R; CAY16
RN3: 1K; CAY16
T1: PMV48XP; SOT-23; PART_NUMBER PMV48XP
U$1: DNP; FRAME
X1: POWERSUPPLY_DC21MMX; POWERSUPPLY_DC-21MM
XIO: 18x2F-H8.5; 2X18
Y1: CSTCE16M0V53-R0; RESONATOR

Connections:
5-GND: RESET.5 (5-GND)
+3V3: C13.2, IC6.5 (OUT), IC7.6 (-IN), POWER.4
+5V: C4.1, C5.1, C6.1, C11.2, D3.C, IC1.2 (OUT), IC1.4 (OUT), IC3.10 (VCC), IC3.31 (VCC1), IC3.61 (VCC2), IC3.80 (VCC3), IC6.1 (IN), IC6.3 (ON/!OFF), IC7.8 (V+), ICSP.2, L2.2, PC2.+, POWER.2, POWER.5, RN1.6 (2), RN1.7 (2), RN3.1, RN5.8 (2), T1.2 (S), XIO.1, XIO.2; also elsewhere on the board
ADC0: ADCL.1, IC3.97 ((ADC0)PF0)
ADC1: ADCL.2, IC3.96 ((ADC1)PF1)
ADC2: ADCL.3, IC3.95 ((ADC2)PF2)
ADC3: ADCL.4, IC3.94 ((ADC3)PF3)
ADC4: ADCL.5, IC3.93 ((ADC4/TCK)PF4)
ADC5: ADCL.6, IC3.92 ((ADC5/TMS)PF5)
ADC6: ADCL.7, IC3.91 ((ADC6/TDO)PF6)
ADC7: ADCL.8, IC3.90 ((ADC7/TDI)PF7)
ADC8: ADCH.1, IC3.89 (PK0(ADC8/PCINT16))
ADC9: ADCH.2, IC3.88 (PK1(ADC9/PCINT17))
ADC10: ADCH.3, IC3.87 (PK2(ADC10/PCINT18))
ADC11: ADCH.4, IC3.86 (PK3(ADC11/PCINT19))
ADC12: ADCH.5, IC3.85 (PK4(ADC12/PCINT20))
ADC13: ADCH.6, IC3.84 (PK5(ADC13/PCINT21))
ADC14: ADCH.7, IC3.83 (PK6(ADC14/PCINT22))
ADC15: ADCH.8, IC3.82 (PK7(ADC15/PCINT23))
AREF: C3.1, IC3.98 (AREF), JP6.3
AVCC: C16.1, IC3.100 (AVCC), L2.1
CMP: C12.2, IC7.5 (+IN), RN5.3 (1), RN5.5 (2)
GATE_CMD: IC7.7 (OUT), T1.3 (G)
GND: C1.2, C2.2, C3.2, C4.2, C5.2, C6.2, C11.1, C12.1, C13.1, C16.2, IC1.1 (GND/ADJ), IC3.11 (GND), IC3.32 (GND1), IC3.62 (GND2), IC3.81 (GND3), IC3.99 (AGND), IC6.2 (GND), IC7.4 (V-), ICSP.6, JP6.4, L.C, ON.C, PC1.-, PC2.-, POWER.6, POWER.7, RESET.1, RESET.2, RN5.4 (1), X1.1, X1.3, XIO.35, XIO.36, Y1.2; also elsewhere on the board
L13: IC7.1 (OUT), IC7.2 (-IN), RN3.7 (2)
unnamed: L.A, RN3.2 (1)
unnamed: ON.A, RN3.8 (2)
PA0: IC3.78 ((AD0)PA0), XIO.3
PA1: IC3.77 ((AD1)PA1), XIO.4
PA2: IC3.76 ((AD2)PA2), XIO.5
PA3: IC3.75 ((AD3)PA3), XIO.6
PA4: IC3.74 ((AD4)PA4), XIO.7
PA5: IC3.73 ((AD5)PA5), XIO.8
PA6: IC3.72 ((AD6)PA6), XIO.9
PA7: IC3.71 ((AD7)PA7), XIO.10
PB0: IC3.19 ((SS/PCINT0)PB0), XIO.34
PB1: IC3.20 ((SCK/PCINT1)PB1), ICSP.3, XIO.33
PB2: IC3.21 ((MOSI/PCINT2)PB2), ICSP.4, XIO.32
PB3: IC3.22 ((MISO/PCINT3)PB3), ICSP.1, XIO.31
PB4: IC3.23 ((OC2A/PCINT4)PB4), JP6.8
PB5: IC3.24 ((OC1A/PCINT5)PB5), JP6.7
PB6: IC3.25 ((OC1B/PCINT6)PB6), JP6.6
PB7: IC3.26 ((OC0A/OC1C/PCINT7)PB7), IC7.3 (+IN), JP6.5
PC0: IC3.53 ((A8)PC0), XIO.18
PC1: IC3.54 ((A9)PC1), XIO.17
PC2: IC3.55 ((A10)PC2), XIO.16
PC3: IC3.56 ((A11)PC3), XIO.15
PC4: IC3.57 ((A12)PC4), XIO.14
PC5: IC3.58 ((A13)PC5), XIO.13
PC6: IC3.59 ((A14)PC6), XIO.12
PC7: IC3.60 ((A15)PC7), XIO.11
PD7: IC3.50 ((T0)PD7), XIO.19
PE0: IC3.2 ((RXD0/PCIN8)PE0), PWML.1; also elsewhere on the board
PE1: IC3.3 ((TXD0)PE1), PWML.2; also elsewhere on the board
PE3: IC3.5 ((OC3A/AIN1)PE3), PWML.6
PE4: IC3.6 ((OC3B/INT4)PE4), PWML.3
PE5: IC3.7 ((OC3C/INT5)PE5), PWML.4
PG0: IC3.51 ((WR)PG0), XIO.22
PG1: IC3.52 ((RD)PG1), XIO.21
PG2: IC3.70 ((ALE)PG2), XIO.20
PG5: IC3.1 ((OC0B)PG5), PWML.5
PH3: IC3.15 (PH3(OC4A)), PWML.7
PH4: IC3.16 (PH4(OC4B)), PWML.8
PH5: IC3.17 (PH5(OC4C)), JP6.10
PH6: IC3.18 (PH6(OC2B)), JP6.9
PL0: IC3.35 (PL0(ICP4)), XIO.30
PL1: IC3.36 (PL1(ICP5)), XIO.29
PL2: IC3.37 (PL2(T5)), XIO.28
PL3: IC3.38 (PL3(OC5A)), XIO.27
PL4: IC3.39 (PL4(OC5B)), XIO.26
PL5: IC3.40 (PL5(OC5C)), XIO.25
PL6: IC3.41 (PL6), XIO.24
PL7: IC3.42 (PL7), XIO.23
PWRIN: D1.A, X1.2
RESET: C1.1, D3.A, IC3.30 (RESET), ICSP.5, POWER.3, RESET.3, RESET.4, RN5.1; also elsewhere on the board
RXD1: COMMUNICATION.3, IC3.45 ((RXD1/INT2)PD2)
RXD2: COMMUNICATION.5, IC3.12 (PH0(RXD2))
RXD3: COMMUNICATION.7, IC3.63 (PJ0(RXD3/PCINT9))
SCL: COMMUNICATION.1, IC3.43 ((SCL/INT0)PD0), JP6.1, RN1.2 (1)
SDA: COMMUNICATION.2, IC3.44 ((SDA/INT1)PD1), JP6.2, RN1.3 (1)
TXD1: COMMUNICATION.4, IC3.46 ((TXD1/INT3)PD3)
TXD2: COMMUNICATION.6, IC3.13 (PH1(TXD2))
TXD3: COMMUNICATION.8, IC3.64 (PJ1(TXD3/PCINT10))
USBVCC: T1.1 (D); also elsewhere on the board
VIN: C2.1, D1.C, IC1.3 (IN), PC1.+, POWER.8, RN5.6 (2)
XTAL1: IC3.34 (XTAL1), R1.1, Y1.3
XTAL2: IC3.33 (XTAL2), R1.2, Y1.1

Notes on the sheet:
(SCK)
(MISO)
(MOSI)
pwm
(TX0)
(RX0)
(SS)
Arturo Guadalupi

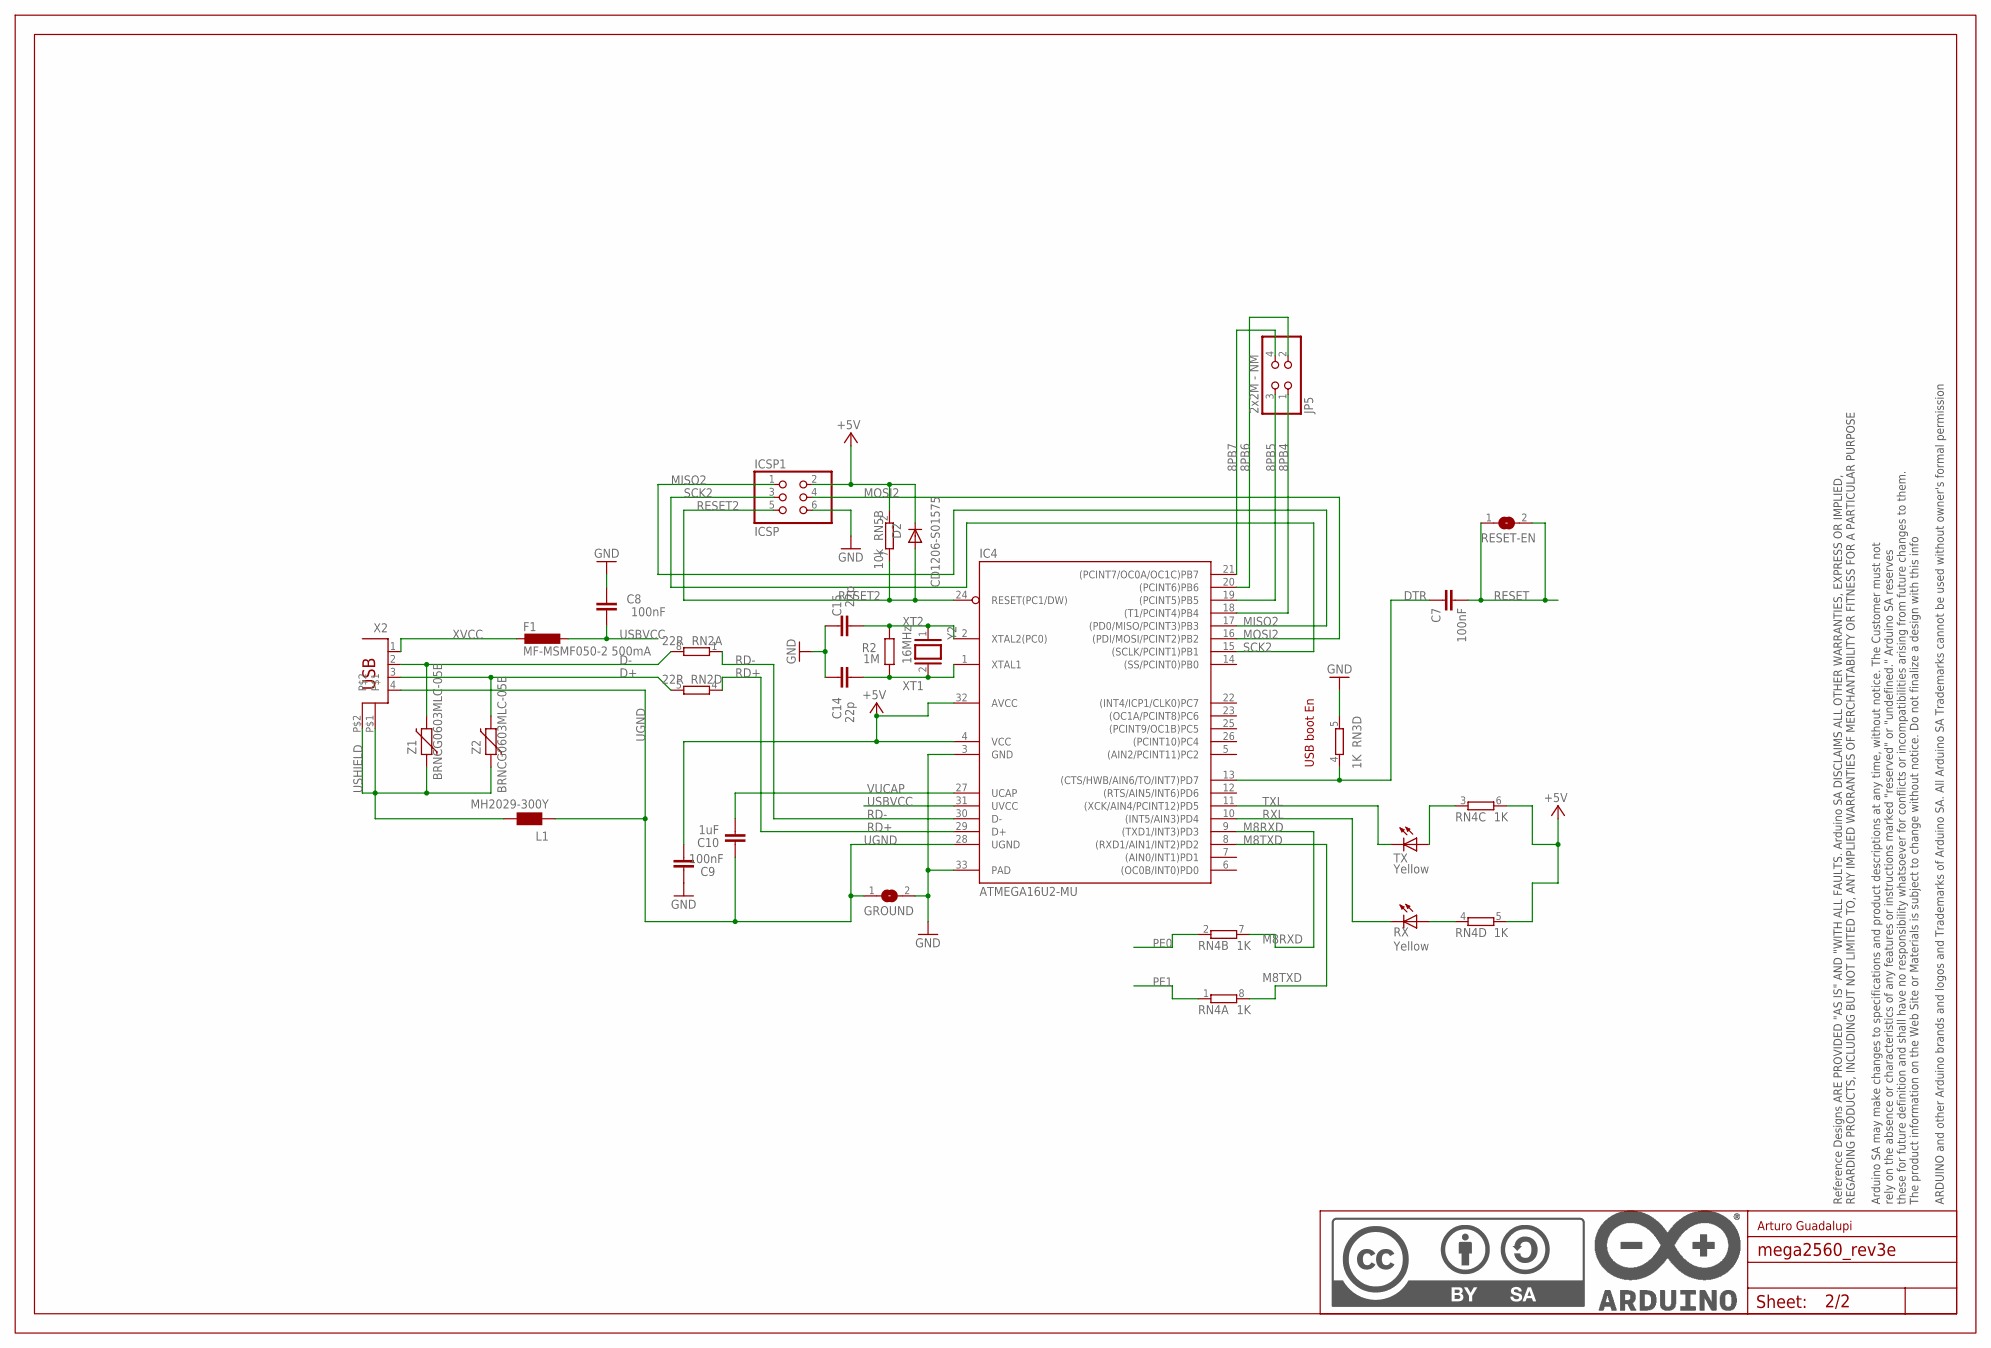
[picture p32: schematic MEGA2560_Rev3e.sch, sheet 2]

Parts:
C7, C8, C9: 100nF; C0603-ROUND
C10: 1uF; C0603-ROUND
C14, C15: 22p; C0603-ROUND
D2: CD1206-S01575; MINIMELF
F1: MF-MSMF050-2 500mA; L1812
GROUND: SJ
IC4: ATMEGA16U2-MU; MLF32
ICSP1: ICSP; 2X03
JP5: 2x2M - NM; 2X02
L1: MH2029-300Y; 0805
R2: 1M; R0603-ROUND
RESET-EN: SJ
RN2: 22R; CAY16
RN3, RN4: 1K; CAY16
RN5: 10k; CAY16
RX: Yellow; CHIPLED_0805
TX: Yellow; CHIPLED_0805
U$2: DNP; FRAME
X2: 0056_USB-B-S-RA-WT-SPCC; PN61729
Y2: 16MHz; QS
Z1, Z2: BRNCG0603MLC-05E; CT/CN0603

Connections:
8PB4: IC4.18 ((T1/PCINT4)PB4), JP5.1
8PB5: IC4.19 ((PCINT5)PB5), JP5.3
8PB6: IC4.20 ((PCINT6)PB6), JP5.2
8PB7: IC4.21 ((PCINT7/OC0A/OC1C)PB7), JP5.4
+5V: C9.1, D2.C, IC4.4 (VCC), IC4.32 (AVCC), ICSP1.2, RN4.5 (2), RN4.6 (2), RN5.2 (1); also elsewhere on the board
D+: RN2.5 (2), X2.3, Z2.2
D-: RN2.8 (2), X2.2, Z1.2
DTR: C7.1, IC4.13 ((CTS/HWB/AIN6/TO/INT7)PD7), RN3.4 (1)
GND: C8.2, C9.2, C14.2, C15.2, GROUND.2, IC4.3 (GND), IC4.33 (PAD), ICSP1.6, RN3.5 (2); also elsewhere on the board
M8RXD: IC4.9 ((TXD1/INT3)PD3), RN4.7 (2)
M8TXD: IC4.8 ((RXD1/AIN1/INT2)PD2), RN4.8 (2)
MISO2: IC4.17 ((PD0/MISO/PCINT3)PB3), ICSP1.1
MOSI2: IC4.16 ((PDI/MOSI/PCINT2)PB2), ICSP1.4
unnamed: RN4.4 (1), RX.A
unnamed: RN4.3 (1), TX.A
PE0: RN4.2 (1); also elsewhere on the board
PE1: RN4.1; also elsewhere on the board
RD+: IC4.29 (D+), RN2.4 (1)
RD-: IC4.30 (D-), RN2.1
RESET: C7.2, RESET-EN.1, RESET-EN.2; also elsewhere on the board
RESET2: D2.A, IC4.24 (RESET(PC1/DW)), ICSP1.5, RN5.7 (2)
RXL: IC4.10 ((INT5/AIN3)PD4), RX.C
SCK2: IC4.15 ((SCLK/PCINT1)PB1), ICSP1.3
TXL: IC4.11 ((XCK/AIN4/PCINT12)PD5), TX.C
UGND: C10.2, GROUND.1, IC4.28 (UGND), L1.1, X2.4
USBVCC: C8.1, F1.1, IC4.31 (UVCC); also elsewhere on the board
USHIELD: L1.2, X2.P$1, X2.P$2, Z1.1, Z2.1
VUCAP: C10.1, IC4.27 (UCAP)
XT1: C14.1, IC4.1 (XTAL1), R2.1, Y2.2
XT2: C15.1, IC4.2 (XTAL2(PC0)), R2.2, Y2.1
XVCC: F1.2, X2.1

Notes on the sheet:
USB boot En
Arturo Guadalupi

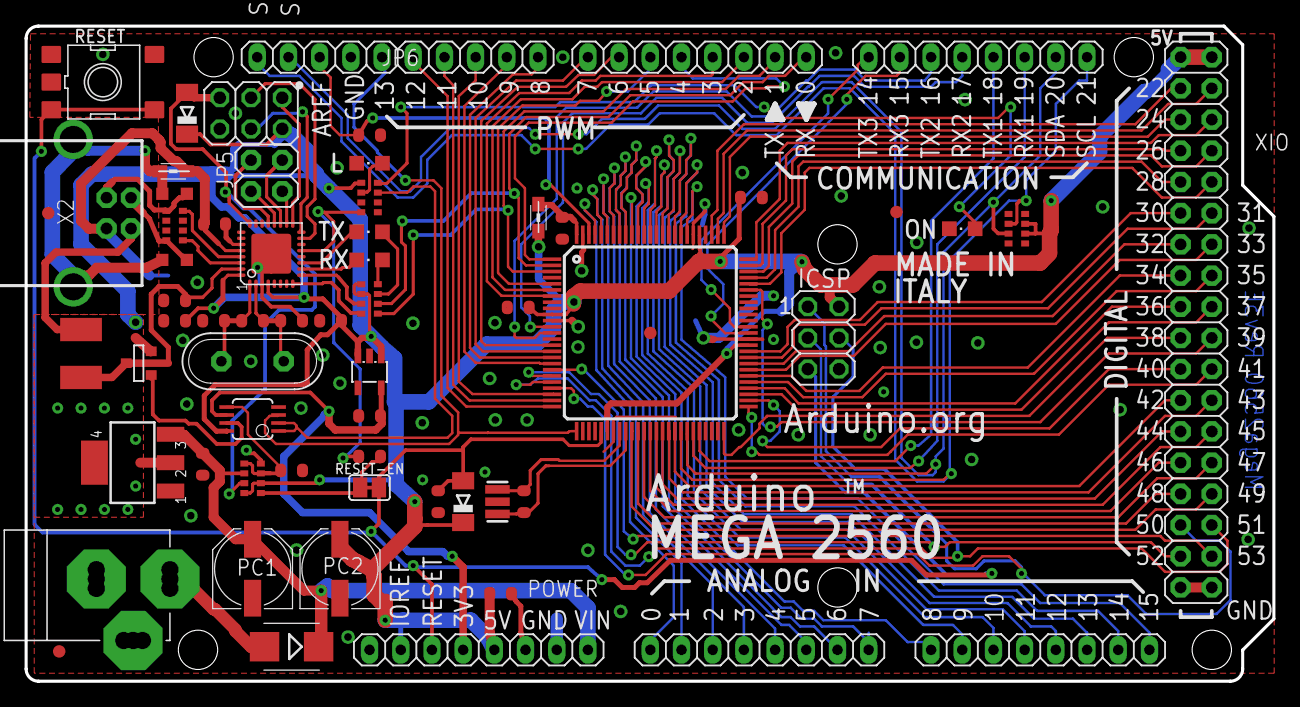
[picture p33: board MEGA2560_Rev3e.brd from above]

Board: 2 copper layers, 101.6 x 53.3 mm, 66 parts (1 on the bottom side), 111 nets.

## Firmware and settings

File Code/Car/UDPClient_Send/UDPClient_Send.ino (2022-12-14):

#include <SPI.h>
#include <Ethernet.h>
#include <EthernetUdp.h>

// Enter a MAC address and IP address for your controller below.
// The IP address will be dependent on your local network:
/*byte mac[] = {
  0xDE, 0xAD, 0xBE, 0xEF, 0xFE, 0xED
};*/

int counter=0;

byte mac[] = {
  0xB8, 0xCA, 0x3A, 0x8B, 0x3B, 0xC6
};
IPAddress ip(192, 168, 88, 254);

unsigned int localPort = 8888;      // local port to listen on

// buffers for receiving and sending data
char packetBuffer[UDP_TX_PACKET_MAX_SIZE];  // buffer to hold incoming packet,
char ReplyBuffer[] = "acknowledged";        // a string to send back

// An EthernetUDP instance to let us send and receive packets over UDP
EthernetUDP Udp;

void setup() {
  // You can use Ethernet.init(pin) to configure the CS pin
  Ethernet.init(10);  // Most Arduino shields
  //Ethernet.init(5);   // MKR ETH shield
  //Ethernet.init(0);   // Teensy 2.0
  //Ethernet.init(20);  // Teensy++ 2.0
  //Ethernet.init(15);  // ESP8266 with Adafruit Featherwing Ethernet
  //Ethernet.init(33);  // ESP32 with Adafruit Featherwing Ethernet

  // start the Ethernet
  Ethernet.begin(mac);

  // Open serial communications and wait for port to open:
  Serial.begin(9600);
//  while (!Serial) {
//    ; // wait for serial port to connect. Needed for native USB port only
//  }

//  // Check for Ethernet hardware present
//  if (Ethernet.hardwareStatus() == EthernetNoHardware) {
//    Serial.println("Ethernet shield was not found.  Sorry, can't run without hardware. :(");
//    while (true) {
//      delay(1); // do nothing, no point running without Ethernet hardware
//    }
//  }
  if (Ethernet.linkStatus() == LinkOFF) {
    Serial.println("Ethernet cable is not connected.");
  }
  Serial.println("Before UDP Begin");
  // start UDP
  Udp.begin(localPort);
  Serial.println("After UDP Begin");
  //Udp.endPacket();
}

void loop() {
  //Serial.println("Beginning of Loop");
  // send a reply to the IP address and port that sent us the packet we received
  Udp.beginPacket(ip, 20001);
  //Serial.println("After Begin Packet");
  Udp.write("TEST");
  //Serial.println("After Write");
  Serial.println(Udp.endPacket());

  Udp.beginPacket(ip, 20001);
  //Serial.println("After Begin Packet");
  String count = "Counter:"+String(counter);
  char Buf[50];
  count.toCharArray(Buf, 50);
  Udp.write(Buf);
  //Serial.println("After Write");
  Udp.endPacket();
  
  Serial.println("Packets Sent. Counter:" + String(counter));

  //incremnet or set counter to 0
  if (counter >=15){
    counter = 0;
  }else{
    counter++;
  }

  Serial.println("Before Delay");
  delay(10);
}


/*
  Processing sketch to run with this example
 =====================================================

 // Processing UDP example to send and receive string data from Arduino
 // press any key to send the "Hello Arduino" message


 import hypermedia.net.*;

 UDP udp;  // define the UDP object


 void setup() {
 udp = new UDP( this, 6000 );  // create a new datagram connection on port 6000
 //udp.log( true );    // <-- printout the connection activity
 udp.listen( true );           // and wait for incoming message
 }

 void draw()
 {
 }

 void keyPressed() {
 String ip       = "192.168.1.177"; // the remote IP address
 int port        = 8888;    // the destination port

 udp.send("Hello World", ip, port );   // the message to send

 }

 void receive( byte[] data ) {      // <-- default handler
 //void receive( byte[] data, String ip, int port ) { // <-- extended handler

 for(int i=0; i < data.length; i++)
 print(char(data[i]));
 println();
 }
 */

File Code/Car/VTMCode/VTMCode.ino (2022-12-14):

//Receive a CAN message and output as a string to UDP
#include <SPI.h>              //Library for using SPI Communication 
#include <mcp2515.h>          //Library for using CAN Communication (https://github.com/autowp/arduino-mcp2515/)
#include <Ethernet.h>         //Library for using Ethernet (https://www.arduino.cc/reference/en/libraries/ethernet/)
#include <EthernetUdp.h>      //Library for sending UDP packets over ethernet

struct can_frame canMsg; // Can message structure for using all CAN functionalities
MCP2515 mcp2515(8);                 // SPI CS Pin 10

byte mac[] = {0xB8, 0xCA, 0x3A, 0x8B, 0x3B, 0xC6}; //mac adress of output device
IPAddress ip(192, 168, 88, 254); //ip adress of output device
unsigned int localPort = 8888;      // local port to listen on

char packetBuffer[UDP_TX_PACKET_MAX_SIZE];  // buffer to hold incoming packet,

EthernetUDP Udp; //DecleareEthernet udp structure for udp/ethernet functionalities

void setup() {
 while (!Serial);
  Serial.begin(115200);       //begin Serial Monitor at baud rate of 115200
  canInitialize(); //intialize mcp 2515 and CAN bus
  Ethernet.init(10);  // tie ethernet to pin 10 !!!! Must change interfears witjh MCP board (This shpuld be moved into udpInitalize() once resolved)
  udpInitialize(); // Initialize udp and ethernet functionalities
  Serial.println("Bootup");
}
void loop() {
  String tempCANstr = canRead(true); //put CAN message into String to then be given to UDP
  if(tempCANstr!= "?"){ //checking if output str is a valid CAN message format
    //Send UDP Packet
    udpSend(tempCANstr); //send CAN messageon UDP
  }
}
//intialize MCP 2515 board
void canInitialize(){
  SPI.begin();               //Begins SPI communication 
  mcp2515.reset();           //reset the board
  mcp2515.setBitrate(CAN_1000KBPS, MCP_8MHZ); //Sets CAN at speed 500KBPS and Clock 8MHz
  mcp2515.setNormalMode();   //set mcp25515 mode to normal
}
//Initialize UDP functionalities
void udpInitialize(){
  Ethernet.begin(mac); //begin ethernet with mac adress input above setup

  if (Ethernet.linkStatus() == LinkOFF) { //check if ethernet cable is fully connected and able to send data
    Serial.println("Ethernet cable is not connected.");
  }
  // start UDP on local port set to "listen" on
  Udp.begin(localPort);
}
//Check if BUS is active
bool checkBus(struct can_frame cn){
  if(mcp2515.readMessage(&cn) == MCP2515::ERROR_OK){
   return true;
  }
  return false;
}
//Receives messages from CAN bus and ouput in string form ("canId,CanLength,data1, data2, data 3,....."), if error reading bus outputs "?" to indicate message not in CAN form
String canRead(bool bol){
  if (mcp2515.readMessage(&canMsg) == MCP2515::ERROR_OK) // To receive data (Poll Read)
  {
    String str = "";
    str += canMsg.can_id; //write CAN message ID to string
    str += ",";
    str += canMsg.can_dlc;//write CAN Message length to string
    str += ",";
    for(int i = 0; i < canMsg.can_dlc; i++){ //go through all the data points using the dlc(length output recieved on line 30) to print out all the data points
      str += canMsg.data[i];
      str += ",";

      //testing
      Serial.print(canMsg.data[i]);
      Serial.print("  ");
    }
    //testing
    Serial.println();

    return str;
  }
  return "?";

}
//Send UDP packet with values put into canM
void udpSend(String canM){
  // Udp.beginPacket("raheelfarouk.tplinkdns.com", 20001); //prepare to send packet in form of EthernetUDP.beginPacket(remoteIP, remotePort);
  Udp.beginPacket(ip, 20001); //prepare to send packet in form of EthernetUDP.beginPacket(remoteIP, remotePort);
  char Buf[canM.length()]; //create char array with length of CAN message
  canM.toCharArray(Buf,canM.length()); //convert can Message string into char array
  Udp.write(Buf); //output char array to UDP
  Udp.endPacket(); //end the packet
}

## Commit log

2022-11-05 Altium Files
    [Microprocessor Module.SchDoc, SAMTEC_TSW-112-07-F-S-LL.PcbLib, TSW-112-07-F-S-LL.SchLib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]
2022-11-05 Update Schematic
    [Microprocessor Module (328).SchDoc, Microprocessor Module_0.SchDoc, Microprocessor Module_1.SchDoc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]
2022-11-17 Add Ethernet Module
    [Ethernet Module.SchDoc, Microprocessor Module (328).PcbDoc, Microprocessor Module (328).SchDoc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]
2022-11-30 Update project
    [Microprocessor Module (328).GBL, Microprocessor Module (328).GBS, Microprocessor Module (328).GKO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]
2022-12-15 Update files
    [ahf12_Amazon_111722_BOM.csv, ahf12_digikey_111722_BOM.csv]
2022-12-16 Update code and upload CAD Files
    [1-5.step.SLDPRT, 1.step.SLDPRT, 2-6.step.SLDPRT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]

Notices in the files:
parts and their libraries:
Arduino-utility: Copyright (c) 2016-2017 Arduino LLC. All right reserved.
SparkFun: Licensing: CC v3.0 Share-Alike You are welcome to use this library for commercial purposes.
